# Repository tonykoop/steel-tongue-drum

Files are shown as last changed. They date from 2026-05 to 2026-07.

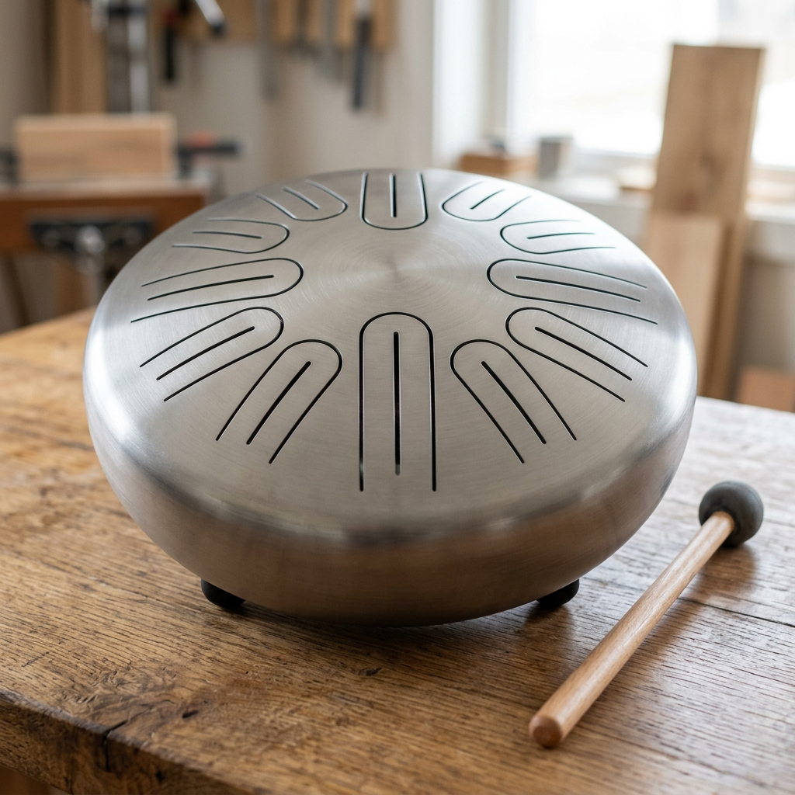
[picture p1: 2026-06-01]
images/hero-render.png

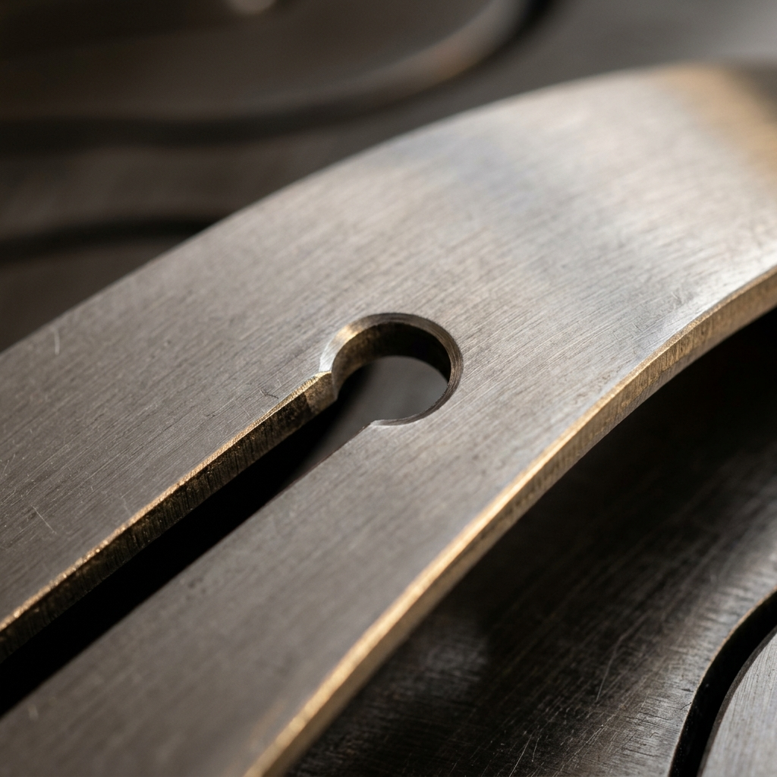
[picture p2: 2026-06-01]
images/macro/tongue-slot-root.png

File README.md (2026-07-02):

# Steel Tongue Drum

Root-mode engineering packet for a tunable steel tongue drum: a slit-tongue steel idiophone whose final tuning must be measured and corrected on the actual prototype.

**Status:** L2 V5 build-packet candidate / prototype planning. This repo is
not L3, measured, or build-ready evidence yet; slot geometry, heat/stress
behavior, tuning response, support shift, finish shift, and safety checks
still require logged prototype measurements.

This repo is part of the [tonykoop/instrument-maker](https://github.com/tonykoop/instrument-maker) catalogue and uses the `instrument-maker-v4` root packet shape.

## What this is

This packet turns the existing `steel-tongue-drum-design-table.xlsx` into a prototype-planning documentation set for a circular steel tongue drum. The workbook provides first-pass geometry, material constants, target MIDI notes, a rough Helmholtz body estimate, and tongue length formulas.

The important caveat: steel tongue drums are empirical instruments. The cantilever equation is useful for rough layout, but final pitch depends on steel batch, residual stress, slot kerf, heat affected zone, burrs, mounting isolation, mallet hardness, finish mass, and the way each tongue is trimmed. This repo is therefore not "tuned" until measured prototype data exists in `validation.csv`.

## Current design baseline

| Item | Baseline |
| --- | --- |
| Body form | Round steel shell / vessel |
| Outside diameter | 12 in assumption from workbook |
| Shell height | 6 in assumption from workbook |
| Steel thickness | 0.079 in derived from workbook input |
| Slot kerf | 0.040 in workbook assumption |
| Tongue width | 1.0 in workbook assumption |
| Port diameter | 2.5 in workbook assumption |
| Tuning reference | A4 = 440 Hz |
| Governing model | `f = K_steel * t / L^2`, first-pass only |
| Validation state | No measured prototype data yet |

## Predicted vs measured

| Category | Current packet status | What still needs physical measurement |
| --- | --- | --- |
| Tongue lengths and target notes | First-pass predictions from the workbook and `design.md` | First-strike Hz, cents error, and trim history for every tongue |
| Steel thickness and K behavior | 0.079 in and workbook K treated as assumptions | Actual sheet thickness, steel grade, and back-solved effective K after tuning |
| Cutting process | Laser / waterjet / CNC options documented | Actual kerf, burr condition, HAZ or taper, and any warp from the chosen process |
| Shell / port behavior | Port and body resonance treated as support variables | Actual port diameter, internal geometry, mount-dependent sustain, and any shell-coupled pitch shift |
| Final readiness | Private-prototype ready packet | Measured rough-cut, deburr, tuning-pass, final-mount, finish-cure, and drift-check data |

## Physical measurements still needed

- Steel grade or best-available supplier spec for the actual blank.
- Thickness measurements at multiple points on the real shell or top plate.
- Kerf coupon results for the chosen cutting method, including burr and taper notes.
- First-strike Hz for bass plus every numbered tongue before trimming.
- Cents error before tuning, after tuning, after final mounting, after finish cure, and after 24-72 hour rest.
- Port diameter and any change after deburring or finish.
- Support-condition notes for temporary cradle versus final feet.

## Packet map

- `design.md` - design intent, assumptions, formulas, tuning workflow.
- `family-spec.csv` - root-mode family row for the current steel tongue drum.
- `bom.csv`, `sourcing.csv`, `cut-list.csv` - purchasing and shop prep.
- `assembly-manual.md` - rough build, cutting, tuning, finish, and mount steps.
- `validation.csv` - tuning and process validation rows, including rough-cut, deburr, first strike, tuning pass, final mount, and drift check.
- `validation-report.md` - current readiness call, acceptance gates, and human-owned measurement work.
- `data/coupon-cam-cad-log.csv` - coupon evidence capture table for CAM/CAD promotion decisions.
- `v5-packet-surface.md` - V5 authority map, no-MCP provenance note, and
  coupon-first promotion gates for issue #5.
- `drawing-brief.md`, `drawings/` - drawing requirements and starter layout SVG.
- `explorer.html` - issue #5 explorer surface for packet status, authority boundaries, and measurement gates.
- `visual-output-register.csv` - visual authority register for the workbook, measurement template, and layout SVG.
- `cad/`, `cnc/`, `jigs/` - SolidWorks/CAM/fixture briefs, the parametric `cad/steel-tongue-drum.scad` build-envelope + tongue-cut-layout master, the issue #5 coupon-first CAM/CAD authority gate, and `cad/mcp-session-log.md` provenance log.
- `evolution/` - StudioPipeline evolution-pipeline Stage 0 intake (master manifest, design-intent, revisions).
- `images/`, `data/`, `wolfram/` - starter folders for future photos, measured results, notebook notes, and the measurement capture plan.
- `issue-comment-draft.md` - sprint-ready issue summary for `tonykoop/steel-tongue-drum#1`; do not post automatically.
- `risks.md` - acoustic, structural, ergonomic, supply, and finish risks with tests.
- `capstone-deck.md`, `print-packet.md`, `print-packet.html`, `site/index.html` - review and presentation layers.

## Readiness

This packet is private-prototype planning ready. It should stay private for public technical review until a rough-cut prototype is struck, tuned, mounted, drift-checked, and logged with measured Hz and cents error.

## Round 3 L2 Boundary

For the Round 3 build-packet sweep, treat this repo as an L2 root-mode packet:
complete enough for design review, sourcing review, and first prototype
planning, but not L3/build-ready evidence. The existing workbook and packet
tables define a controlled measurement path; they do not replace measured
strike data from a real steel shell.

The acceptance line for L3 is unchanged: every tongue needs target Hz, measured
Hz, cents error, support condition, trim history, final mount shift, finish
shift, and 24-72 hour drift logged in `validation.csv`.

## Issue 5 CAM/CAD Coupon Gate

Issue #5 is not complete yet. The repo now has an explicit
`cnc/coupon-first-cam-cad-gate.md` and `data/coupon-cam-cad-log.csv` so the
first coupon can promote or block CAD/DXF/CAM decisions with evidence. Until
that coupon row contains real material, kerf, taper, burr/HAZ/warp, and strike
measurements, the starter SVG, workbook, CAD brief, and CNC brief remain
documentation and prototype-planning artifacts only.

Round 2 recovery adds the V5 packet surface without changing that authority
boundary: `visual-output-register.csv` now marks current geometry-related rows
as `pending_measurement` or `concept_only`, and `cad/mcp-session-log.md`
records that no MCP/CAD/measurement tool session was available or used.

## License

[CC BY 4.0](LICENSE) - see LICENSE for details.

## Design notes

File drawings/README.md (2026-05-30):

# Drawings

This folder is reserved for future manufacturable drawings and exported views.
The current SVG is a starter layout brief, not a final tuned DXF.

Required future exports:

- Top slot layout DXF/SVG with actual kerf compensation.
- Section view through shell, port, and support feet.
- Slot-root detail with minimum radius and burr limit.
- Fixture/cradle drawing.

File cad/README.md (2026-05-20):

# CAD Starter

CAD should be driven from the workbook and `family-spec.csv`, but final tuned slot geometry must come from measured prototype correction.

Current status for issue #5: no repo-local coupon evidence exists yet, so CAD
is still a starter brief and not machine-ready authority. Use
`cnc/coupon-first-cam-cad-gate.md` and `data/coupon-cam-cad-log.csv` before
promoting any CAD/DXF export.

## Suggested Files

- `STD-001_MasterLayout.SLDPRT` - master sketch with shell, port, tongues, root radii, and datum axes.
- `STD-001_TongueField.DXF` - waterjet/laser/CNC export after kerf compensation.
- `STD-001_ValidationCoupon.DXF` - kerf and HAZ test coupon.

## Global Variables

- `BodyDiameter = 12 in`
- `ShellHeight = 6 in`
- `SteelThickness = measured actual`
- `KerfWidth = measured process value`
- `TongueWidth = 1 in`
- `PortDiameter = 2.5 in`

Do not lock CAD dimensions as final tuned values until `validation.csv` has measured data.
Do not mark `STD-001_TongueField.DXF` or any CAM export as build-ready until a
validation coupon has measured kerf, edge condition, and process notes logged.

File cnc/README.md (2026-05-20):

# CNC / Cutting Plan

## Preferred Prototype Path

Do not start with the full tongue field. Start with a coupon that uses the same material, process, and nominal kerf as the intended build. The coupon's job is to reveal real kerf, edge taper, burr behavior, and whether the chosen process pushes the first strike noticeably sharp or flat before the actual drum is cut.

Issue #5 gate file: `coupon-first-cam-cad-gate.md`.
Coupon evidence log: `../data/coupon-cam-cad-log.csv`.

## Process Comparison

| Process | Strength | Risk | Required validation |
| --- | --- | --- | --- |
| Waterjet | Low heat input | Edge taper, abrasive texture, burr | Measure slot width top and bottom, log burr cleanup, compare first strike before and after deburr |
| Fiber laser | Fast, accurate | HAZ, stress, warp, hard edge | Photograph discoloration, check flatness, and compare coupon pitch before and after stress relief |
| CNC mill | Controlled geometry | Fixturing thin steel, chatter, burrs | Prove hold-down, coolant/chip control, and slot finish on coupon before real cutting |
| Manual abrasive | Accessible | Low repeatability | Use only for tuning corrections, not full layout |

## Coupon-First Validation Path

1. Cut a simple coupon with one representative tongue, one slot-end radius, and one kerf sample.
2. Measure actual kerf at multiple points and record top/bottom taper if present.
3. Deburr in the intended shop sequence and note whether measured pitch changes.
4. Inspect the slot root for cracks, gouges, or over-thinning.
5. Only then cut the real top or shell tongue field.

## Manufacturing Release Gates

- The first setup must include a coupon or sacrificial strip.
- Every slot end must be radiused; no sharp internal corners.
- The layout must keep a stable orientation mark and datum so the tuning log matches the physical instrument.
- Actual kerf and any CAM compensation must be written into `validation.csv` or `data/measurement-capture-plan.md`.
- The coupon result and CAM compensation decision must be written into `data/coupon-cam-cad-log.csv`.
- No file in this folder should be described as build-ready G-code until coupon evidence and first-strike measurements exist.

## CAM Notes

- Use rounded slot termini.
- Avoid sharp internal corners.
- Keep a consistent datum/orientation mark.
- Include the validation coupon in the first setup.
- Document actual kerf and any compensation used.

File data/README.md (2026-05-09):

# Data

Measured steel tongue drum results should be stored here once cutting and tuning begin.

## Expected Artifacts

- Rough-cut and post-deburr pitch logs.
- Kerf coupon measurements and process notes.
- Before/after tuning pass results.
- Final-mount and drift-check readings.
- Photos or screenshots that support `validation.csv` entries.
- The filled measurement path from `measurement-capture-plan.md`.

## Current Status

No measured prototype data exists yet. The repo is documentation-complete enough to guide a build, but this folder should remain empty until a real prototype is logged.

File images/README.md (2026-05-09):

# Images

This folder is reserved for public-safe build photos, validation setup photos, and final hero shots once a real prototype exists.

## Priority Shots

- Raw shell or blank with steel spec visible.
- Thickness-caliper confirmation.
- Layout before cutting.
- Rough-cut and deburred tongue roots.
- First-strike tuner setup.
- Final mounted underside and finished top view.

## Current Status

No real prototype photos exist yet. Until then, `drawings/steel-tongue-drum-layout.svg` and the site packet carry the visual explanation.

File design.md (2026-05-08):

# Steel Tongue Drum Design

Generated: 2026-05-08

## Intent

Create a traceable root-mode packet for a tuned steel tongue drum. The packet documents the first-pass geometry from `steel-tongue-drum-design-table.xlsx`, the manufacturing assumptions that can move pitch, and the validation workflow needed to turn estimates into a tuned instrument.

This design is intentionally conservative about claims. The workbook formulas size tongues from a cantilever model, but the final instrument must be tuned by measured cutting and strike tests.

## Source Artifacts

| Source | Role | Status |
| --- | --- | --- |
| `steel-tongue-drum-design-table.xlsx` | Design table and first-pass geometry | Present |
| `README.md` | Root repo overview | Expanded in this packet |
| `instrument-maker-v4` references | Physics, sourcing, print packet, validator | Applied |
| Measured prototype data | Required for final tuning confidence | Not present |

## Workbook Inputs Used

| Parameter | Value | Unit | Source / confidence |
| --- | ---: | --- | --- |
| Shell outside diameter | 12.000 | in | workbook input, assumption |
| Shell height | 6.000 | in | workbook input, assumption |
| Steel thickness | 0.079 | in | workbook input, verify with calipers |
| Kerf width | 0.040 | in | workbook input, process-dependent |
| Tongue count | 11 | count | workbook note rows include bass row plus 10 numbered rows |
| Tongue width | 1.000 | in | workbook input, derived estimate |
| Port diameter | 2.500 | in | workbook input, derived estimate |
| Tuning standard | 440 | Hz | A4 reference |
| Selected K constant | 32098 | imperial | workbook steel table, first-pass only |

## Governing Model

Use the cantilever beam model only as an initial layout estimate:

```text
f = K_steel * t / L^2
L = sqrt(K_steel * t / f)
```

Where:

- `f` is target frequency in Hz.
- `K_steel` is the workbook steel constant, currently 32098 for the selected steel row.
- `t` is steel thickness in inches.
- `L` is free tongue length in inches.

The model assumes an ideal fixed-free tongue. A real steel tongue drum departs from that ideal because the tongue remains part of a stressed plate/shell, is cut by a finite kerf, may be heat affected, may retain burrs, and is coupled to the vessel body and support system.

## Target Tongue Table

The values below are first-pass estimates from the workbook formula family. Treat every length as a starting cut length with trim allowance, not a final tuned dimension.

| Tongue | MIDI | Note | Target Hz | Derived length in | Derived length mm | Status |
| ---: | ---: | --- | ---: | ---: | ---: | --- |
| Bass | 50 | D3 | 146.83 | 4.16 | 105.6 | derived estimate |
| 1 | 57 | A3 | 220.00 | 3.39 | 86.2 | derived estimate |
| 2 | 58 | A#3/Bb3 | 233.08 | 3.30 | 83.7 | derived estimate |
| 3 | 60 | C4 | 261.63 | 3.11 | 79.0 | derived estimate |
| 4 | 62 | D4 | 293.66 | 2.94 | 74.6 | derived estimate |
| 5 | 64 | E4 | 329.63 | 2.77 | 70.4 | derived estimate |
| 6 | 65 | F4 | 349.23 | 2.69 | 68.4 | derived estimate |
| 7 | 67 | G4 | 392.00 | 2.54 | 64.5 | derived estimate |
| 8 | 69 | A4 | 440.00 | 2.40 | 60.9 | derived estimate |
| 9 | 72 | C5 | 523.25 | 2.20 | 55.9 | derived estimate |
| 10 | 74 | D5 | 587.33 | 2.08 | 52.8 | derived estimate |

## Shell / Helmholtz Estimate

The workbook includes a first-pass vessel estimate using a 12 in diameter, 6 in high partial volume assumption and a 2.5 in port. This is useful for checking whether the shell may reinforce or color the tongue field, but it should not be treated as a final resonator design.

For this packet, the shell resonance is documented as a support variable:

- Verify actual internal volume after forming, welding, or purchased shell selection.
- Measure the port diameter after deburring and finish.
- Compare struck tongue spectra mounted and unmounted.
- Record whether final mounting shifts pitch or sustain.

## Empirical Tuning Workflow

1. Rough-cut the tongues long or conservative, with rounded stress-relief termini.
2. Deburr both sides without thinning the root unpredictably.
3. Strike each tongue with the same mallet and support condition.
4. Log measured Hz and cents error in `validation.csv`.
5. Remove material in controlled passes, favoring tip/length correction first.
6. Re-measure after each tuning pass and after final mounting.
7. Re-check drift after finish cure and 24-72 hours of rest.

## Manufacturing Assumptions

- Steel grade is not locked. Mild low-carbon sheet is the default planning case; stainless is acceptable only after revisiting K, cutting method, corrosion plan, and work hardening behavior.
- Thickness must be measured at the actual blank, not assumed from nominal sheet gauge.
- Laser cutting is fast but risks heat affected zones and local stress changes.
- Waterjet cutting reduces heat risk but can leave taper, abrasive edge texture, and local burrs.
- CNC milling can control slot geometry but needs serious fixturing and coolant/chip planning on thin steel.
- Every inside slot end needs a smooth radius to reduce crack initiation.

## Unresolved Tuning Assumptions

- Actual steel grade, modulus, density, hardness, and residual stress.
- Actual kerf after the chosen cutting process.
- Whether the blank is flat sheet, preformed shell, salvaged vessel, or welded assembly.
- Final support/isolation scheme.
- Mallet hardness and strike point standard.
- Finish mass and corrosion-protection method.
- Whether the bass tongue and high tongues remain balanced in volume and sustain after final trimming.

## Acceptance Criteria

The packet becomes public-review ready only after:

- Each tongue has target Hz, measured Hz, cents error, mallet condition, support condition, and environment logged.
- Rough-cut, deburr, first strike, tuning pass, final mount, and drift check rows are complete.
- At least one process note records actual kerf, burr condition, and heat/warp observations.
- `validation-report.md` is updated from measured data rather than assumptions.

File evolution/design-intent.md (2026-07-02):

# Design Intent — steel-tongue-drum rev A

- Master CAD: `cad/steel-tongue-drum.scad` (sha256: 0e1638eccd13ec92ad5bc1255719e85c75dedc66023e533947869e00f35b9f05), driven by `steel-tongue-drum-design-table.xlsx` (sha256: e1663ea1faadcabe5026d6eda636c8874fcc8eba346b22df14e118949e094d0b).
- Function: Tuned steel tongue drum (idiophone). A 12 in OD × 6 in vessel with a 0.079 in steel top plate carrying 11 radial cantilever tongues (bass D3 plus a D-centered mixed pentatonic/diatonic field to D5), struck with mallets/hands; a 2.5 in port colors the coupled shell resonance. Each tongue's pitch follows the fixed-free cantilever model f = K·t/L² (design.md Governing Model); final pitch is set empirically by trimming length. See design.md.
- Environment: indoor idiophone. Tongues are stressed plate cantilevers taking repeated strike impact; steel grade/heat treatment and cut process (laser HAZ vs waterjet taper) move pitch and crack risk.
- Target qty: 1 (root prototype). Deadline: TBD. Budget/unit ceiling: TBD.

## Critical dimensions (carry tolerances)

| Feature | Nominal | Tolerance | Why critical | Source |
| --- | --- | --- | --- | --- |
| Steel thickness t | 0.079 in | verify w/ calipers on actual blank | sets every tongue pitch (f∝t) | design.md Workbook Inputs / family-spec.csv |
| Tongue free lengths | D3 4.16 in .. D5 2.08 in | rough-cut long, tune by trim | tongue pitch (L=sqrt(K·t/f)) | design.md Target Tongue Table |
| Kerf width | 0.040 in | measured process value (coupon) | tongue width margin, tuning | design.md / cad/README.md |
| Tongue width | 1.0 in | layout | radiation/sustain balance | design table |
| Shell OD / height | 12.0 / 6.0 in | after forming/selection | coupled shell resonance | family-spec.csv |
| Port diameter | 2.5 in | after deburr/finish | Helmholtz coloration | design.md Shell/Helmholtz |

## Incidental (free for DFM)

- Exact tongue angular clocking (even fan preserved), shell wall finish, port trim styling, mounting/isolation hardware, foot/stand interface.

## Must-nots (DFM may never violate)

- Every inside slot end MUST get a smooth stress-relief radius — square slot ends initiate cracks (design.md Manufacturing Assumptions).
- Do NOT lock CAD tongue lengths as final tuned values; rough-cut long and trim to measured pitch (design.md / cad/README.md).
- Do NOT mark any tongue-field DXF/CAM export build-ready until the coupon gate (data/coupon-cam-cad-log.csv) logs measured kerf, edge condition, and HAZ (cad/README.md).
- Do NOT switch steel grade (mild → stainless) without revisiting K, cutting method, corrosion plan, and work-hardening (design.md).

## Material intent

- Preferred: mild low-carbon steel top plate/shell (default planning case). Stainless acceptable only after re-deriving K and cut process.
- Acceptable subs: per sourcing.csv (spec-first; live prices unverified).
- Forbidden: assuming nominal sheet gauge instead of measured thickness; square (un-radiused) slot terminations.

## Stage status

Stage 0 intake complete 2026-07-01. Gate A (Alpha shop compile) NOT yet run — no concessions logged, nothing presented as shippable. All tongue lengths remain first-pass estimates (no measured prototype data).

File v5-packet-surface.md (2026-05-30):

# V5 Packet Surface - Steel Tongue Drum

Status: `L2 V5 build-packet candidate; pending measurement`.

Issue: Refs #5.

This file defines the honest V5 surface for the steel tongue drum packet. It is
a structure and authority map only. It does not add CAD geometry, DXF
coordinates, CAM setup values, measured partials, or tuning frequencies.

## Authority Summary

| Surface | Current authority | Why it is not L3 |
| --- | --- | --- |
| Workbook and family spec | `pending_measurement` | Values are workbook assumptions and first-pass planning inputs; real steel thickness, kerf, stress, and tuning response are not measured. |
| Starter SVG | `concept_only` | It is a human preview, not a DXF, CAD source, or CAM input. |
| Coupon log | `pending_measurement` | `STD-COUPON-001` is `not_run`; no material, kerf, taper, burr, HAZ, warp, or strike evidence exists. |
| Validation CSV | `pending_measurement` | It is a measurement template with open rows, not a measured performance record. |
| MCP/CAD provenance | `concept_only` | `cad/mcp-session-log.md` records that no external tool session was run in this lane. |

## Coupon-First Protocol

Before promoting any CAD, DXF, CAM, or G-code claim:

1. Select the actual material blank and record supplier/spec information or
   explicitly mark the grade unknown.
2. Measure real thickness at multiple points and record the instrument state
   used for measurement.
3. Cut a representative coupon with the same process intended for the drum.
4. Measure kerf at multiple points and record top/bottom taper or edge angle
   if visible.
5. Record burr, heat affected zone, discoloration, warp, and slot-root
   condition.
6. Strike the coupon before and after deburring only if the coupon geometry is
   safely strikeable.
7. Enter the compensation decision in `data/coupon-cam-cad-log.csv`.
8. Update `validation-report.md` before any artifact changes from
   `pending_measurement` to fabrication authority.

## V5 Gate Table

| Gate | Required evidence | Current state |
| --- | --- | --- |
| G1 material evidence | Actual blank source and measured thickness | Pending |
| G2 coupon cut | Coupon made with intended process | Pending |
| G3 kerf/taper evidence | Measured kerf and edge notes | Pending |
| G4 burr/HAZ/warp evidence | Inspection notes or photos | Pending |
| G5 coupon strike evidence | Pre/post deburr Hz if safely strikeable | Pending |
| G6 CAM compensation decision | Keep/change kerf, slot radius, or process | Blocked by G1-G5 |
| G7 full tongue-field release | Reviewed coupon result and updated register | Blocked by G6 |
| G8 tuned-instrument claim | Full `validation.csv` first-strike, trim, mount, finish, and drift data | Blocked by physical build |

## What Is Needed Next

- Run the physical coupon protocol and populate `data/coupon-cam-cad-log.csv`.
- Add real evidence paths for photos, measurement sheets, or shop notes.
- Update `visual-output-register.csv` only after measurement evidence exists.
- Replace or regenerate CAD/DXF artifacts from reviewed authority before any
  build-ready claim.
- Keep the packet at L2 until the measurement and CAD authority chain is
  complete.

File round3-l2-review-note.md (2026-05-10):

# Round 3 L2 Review Note

This repo already contains a validator-clean root-mode packet. Round 3 keeps it
at L2 for review discipline:

- The cantilever model and workbook geometry are first-pass estimates.
- No rough-cut steel shell measurements have been captured.
- No tuning-pass, final-mount, finish-cure, or drift-check data exists.
- `validation.csv` is the gate for L3, not the presence of packet files.

Acoustic basis: `instrument-maker-v4/references/new-instruments-v4.md` section
`Steel Tongue Drum` identifies the steel tongue as a cantilever-beam model,
while `references/acoustic-models.md` warns that ceramic/metal tongue drums
need material-specific measurement loops.

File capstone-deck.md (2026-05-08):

# Steel Tongue Drum Capstone
- Musical instrument documentation capstone
- Build packet: steel-tongue-drum
- Generated: 2026-05-08

---

# Project Intent
- Create a traceable root-mode packet for a tuned steel tongue drum. The packet documents the first-pass geometry from `steel-tongue-drum-design-table.xlsx`, the manufacturing assumptions that can move pitch, and the validation workflow needed to turn estimates into a tuned instrument.

_Speaker notes:_ Read design.md before committing to dimensions or sourcing decisions.

---

# Physics Model
- Use the cantilever beam model only as an initial layout estimate:

```
f = K_steel * t / L^2
L = sqrt(K_steel * t / f)
```

_Speaker notes:_ Governing equations extracted verbatim from design.md. Apply empirical corrections (NAF K2, scale offsets) only where the model permits — see references/acoustic-models.md.

---

# How To Use This Packet
- Start with design.md for intent and assumptions.
- Use bom.csv, sourcing.csv, and cut-list.csv before buying or cutting.
- Use drawing-brief.md and CAD/CNC folders before machining.
- Print the packet for shopping, shop work, and validation.

---

# File Map
- design.md: Project intent, catalog metadata, assumptions, and validation plan.
- bom.csv: Starter bill of materials with part categories, quantities, drawing refs, and notes.
- sourcing.csv: Supplier/search tracker with specs, price/date fields, lead time, substitutes, and risks.
- cut-list.csv: Rough/final stock sizes, material, grain/orientation, operations, yield, and offcuts.
- drawing-brief.md: Manufacturing drawing and technical product sketch brief.
- assembly-manual.md: Shop-facing sequence, tools, fixtures, safety, tuning, finishing, and maintenance notes.
- validation.csv: Target/measured values, tolerance, environment, result, and tuning/build action log.
- supplier-rfq.md: Supplier email/request-for-quote starter.

---

# Family Spec

| family_id | member_id | instrument_name | variant | key_or_scale | body_diameter_in | shell_height_in | steel_thickness_in | tongue_count | port_diameter_in | design_stage | validation_state | notes |
| --- | --- | --- | --- | --- | --- | --- | --- | --- | --- | --- | --- | --- |
| STD-FAM-001 | STD-001 | Steel Tongue Drum | 12 inch root prototype | D-centered mixed pentatonic/diatonic study | 12.0 | 6.0 | 0.079 | 11 | 2.5 | root-mode packet | no measured prototype data | Derived from steel-tongue-drum-design-table.xlsx; final tuning empirical. |

_Speaker notes:_ Sizes scale via the master scale factor; tuning targets are first-order Helmholtz/cantilever predictions to be empirically corrected per prototype.

---

# Build Workflow
- Design and assumptions
- Source materials and hardware
- Prepare stock, fixtures, and CNC/laser/lathe setup
- Assemble, tune, finish, and validate

---

# Sourcing And BOM
- BOM gives part categories and drawing references.
- Sourcing tracks search terms, supplier candidates, price/date, lead time, substitutions.
- Visual BOM brief turns the parts list into a presentation-ready image board.

---

# Shop Packet
- Cut list for lumber/sheet/blank planning.
- Assembly manual for away-from-keyboard work.
- Validation sheet for measured dimensions, tuning, pass/fail checks.

---

# Drawings, CAD, CNC
- drawing-brief.md defines required views, dimensions, datums, sketch intent.
- cad/ holds models and design tables.
- cnc/ holds CAM, toolpaths, setup sheets, dry-run notes.
- drawings/ holds PDFs, SVGs, DXFs, drawing exports.



---

# Images And Screenshots
- Add hero render/photo, visual BOM, shop screenshots, drawing previews, validation photos in images/.

---

# Validation Plan
- A4 = 440 Hz reference check.
- Tuning targets logged in validation.csv.
- Critical dimensions verified against design sheet and CAD.
- Photos and revision notes after each major step.

---

# Open Risks / Decisions
- TBDs in design sheet and BOM.
- Supplier price/availability not yet verified.
- Generated images marked as concept placeholders.
- Empirical corrections await measured prototype data.

---

# Next Actions
- Replace TBDs with measured/source-backed values.
- Verify live supplier price and availability before buying.
- Export final drawings and visual BOM images.
- Regenerate this deck and print packet after final edits.

---

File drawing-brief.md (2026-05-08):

# Drawing Brief

## Required Drawing Set

1. Top layout with all tongue slots, centerline, port, rim, and orientation mark.
2. Section view through shell showing top thickness, shell height, port, support feet, and rim/edge treatment.
3. Detail view of a tongue root with slot-end radius, kerf, burr limit, and stress-relief note.
4. Fixture view showing temporary tuning support and final isolation feet.
5. Process coupon drawing for kerf and HAZ validation.

## Critical Dimensions

- 12.0 in body diameter assumption.
- 6.0 in shell height assumption.
- 0.079 in steel thickness assumption.
- 0.040 in kerf assumption.
- 1.0 in tongue width assumption.
- 2.5 in port diameter assumption.
- Tongue lengths from `design.md` are derived estimates and must be marked "rough-cut; tune by measurement."

## Drawing Rules

- Units: inches with metric equivalents where useful.
- Include title block, revision, date, material, finish, and "not final tuned dimensions" note.
- Show datum A as top center, datum B as rim plane, datum C as orientation line.
- Call out all inside slot ends as smooth radiused transitions.
- Do not publish as final manufacturing drawing until validation data exists.

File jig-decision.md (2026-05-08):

# Jig Decision

## Decision

Use a two-stage jig approach:

1. A non-marring temporary tuning cradle that supports the shell consistently while leaving the tongue field free.
2. A final isolation-foot layout that is re-measured after installation.

## Why

The support condition is part of the instrument. A rigid clamp, bench pad, hand hold, rubber foot, and display stand can all change damping and perceived pitch. Separating the temporary tuning cradle from the final mount makes that shift visible in `validation.csv`.

## Requirements

- Cradle must locate the shell repeatably without contacting vibrating tongues.
- Contact points should be soft enough to prevent rattles but stable enough for repeatable measurements.
- Fixture should expose the port and underside for inspection.
- Final feet must be installed before the final-mount validation phase.

## Rejected Options

- Freehand holding during tuning: too variable.
- Clamping the shell rigidly to a bench: likely to damp shell modes.
- Tuning only after final finish: hides process causes and makes correction harder.

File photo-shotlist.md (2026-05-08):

# Photo Shotlist

- Raw steel shell or blank with label/spec visible.
- Caliper reading of actual steel thickness.
- Layout on top surface before cutting.
- Kerf coupon or test cut close-up.
- Rough-cut slots before deburring.
- Deburred slot root close-up with light showing radius.
- Temporary tuning support setup.
- Tuner/microphone placement during first strike.
- Tuning pass in progress with tool and tongue identified.
- Final feet or isolation mount underside.
- Finished top view with all tongues visible.
- Detail of port, rim, and edge trim.

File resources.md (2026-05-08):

# Resources

## Local Packet Sources

- `steel-tongue-drum-design-table.xlsx` - workbook source for dimensions, K constants, target notes, and formulas.
- `design.md` - narrative design basis and assumptions.
- `validation.csv` - required measurement log.
- `drawings/steel-tongue-drum-layout.svg` - starter layout drawing.

## Instrument Maker References

- `instrument-maker-v4/references/new-instruments-v4.md` - steel tongue drum entry.
- `instrument-maker-v4/references/acoustic-models.md` - cantilever beam formulas and guard rules.
- `instrument-maker-v4/references/manufacturing-and-cnc.md` - machining and fixture guidance.
- `instrument-maker-v4/references/sourcing-and-production.md` - sourcing, RFQ, cut list, validation guidance.

## Sister Repos

- `tongue-drum` - wooden slit tongue drum done-bar reference and DoE pattern.
- `glockenspiel` - metal bar idiophone sibling concept.
- `handpan` - steel shell idiophone sibling, but different governing model.

## Measurement Tools To Use

- Chromatic tuner or spectral analysis app.
- Calipers for thickness, kerf, port, and slot checks.
- Consistent microphone placement.
- Temperature/humidity record for each tuning session.

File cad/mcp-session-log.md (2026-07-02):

# MCP Session Log

Status: `no tool session run`.

This V5 provenance stub is intentionally empty of CAD or creative-tool output.
The Round 2 recovery lane had no MCP, OpenSCAD, Blender, Illustrator,
Photoshop, Fusion, SolidWorks, Wolfram execution, or physical measurement
session available. No CAD geometry, DXF coordinates, tuning frequencies, or
measured dimensions were generated in this lane.

| session_id | tool | input_authority | outputs | role | authority_result | review_status | notes |
| --- | --- | --- | --- | --- | --- | --- | --- |
| NO-MCP-2026-05-29-R2 | none | `visual-output-register.csv`; `cnc/coupon-first-cam-cad-gate.md`; `data/coupon-cam-cad-log.csv` | none | provenance_stub | concept_only | self_checked | Records absence of tool execution; all geometry and tuning authority remains pending measurement. |
| fable-v5-refresh-2026-07-01 | claude-code (Fable 5) + OpenSCAD CLI | steel-tongue-drum-design-table.xlsx, design.md, family-spec.csv | cad/steel-tongue-drum.scad | cad_authoring | pending_measurement | self_checked | Parametric build-envelope + tongue-cut LAYOUT master (equation-driven L=sqrt(32098*t/f)). openscad render check: pass (openscad -o STL, exit 0, Simple: yes). NOT fabrication authority — kerf/slot-radii/HAZ/tuned-trim out of scope pending coupon gate. |
| fable-v5-refresh-2026-07-01 | claude-code (Fable 5) | steel-tongue-drum-design-table.xlsx | wolfram/steel-tongue-drum-wolfram-model.wl | analysis_source | derived_preview | unreviewed | Register row added for the epic197-deployed Wolfram model source; not executed — source-only L2 evidence. |

## Promotion Rule

If a future lane uses OpenSCAD, Blender, Illustrator, Photoshop, Fusion,
SolidWorks, Wolfram, or another external tool to create or modify packet
artifacts, add a real session row before describing any output as reviewed,
derived, or fabrication authority.

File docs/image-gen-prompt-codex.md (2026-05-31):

# Image-Gen Prompt - Steel Tongue Drum

Concept image only; not fabrication authority. Do not include cut-ready dimensions, tongue slot coordinates, port patterns, or toolpaths.

## Hero Prompt

Photorealistic studio product photograph of a finished circular steel tongue drum with a rounded steel shell, eleven slit-cut tongues including a larger bass tongue, a small resonating port, smooth deburred slot ends, satin powder-coated or brushed finish, and a pair of soft mallets resting nearby. Show realistic handpan-like scale without copying a brand, clean studio background, three-quarter product angle from above, soft directional studio lighting, approximately 50mm lens, high detail.

## In-Context Prompt

Photorealistic image of the steel tongue drum being played on a lap or low stand in a quiet recording room, soft mallets striking two different tongues, natural light, a tuner and validation notebook blurred nearby, realistic posture, rounded safe edges, calm prototype-review atmosphere.

## Detail/Macro Prompt

Macro photorealistic close-up of a single slit tongue and neighboring slots, showing rounded stress-relief termini, deburred edge, subtle finish texture, soft mallet tip just above the tongue, and shallow curvature of the steel shell, shallow depth of field, crisp highlights.

## Negative/Avoid

No text, no watermarks, no brand marks, no fake note labels, no cut-ready tongue layout, no sharp burrs or cracked slots, no extra limbs, anatomically plausible hands.

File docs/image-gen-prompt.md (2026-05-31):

# Image-Gen Prompts

Concept image only; not fabrication authority. Do not include cut-ready dimensions, hole locations, or toolpaths.

## Hero Prompt

A finished circular steel tongue drum photographed as a real, hand-built idiophone: a round low-profile steel shell, roughly the proportions of a small drum that fits in two hands, with a domed or gently rounded top plate cut with a radial fan of eleven slit tongues of graduated length splaying out from the center toward the rim. The tongues read clearly as cut slots in the steel surface, each terminating in a smooth rounded slot-end, the longest bass tongue prominent and the shorter high tongues stepping down in size around the field. Brushed low-carbon steel with a subtle satin clear finish, faint mill grain catching the light, softly radiused rim, no welds or seams emphasized. Three rubber feet barely visible at the base lift the body slightly off the surface. Realistic tabletop scale cues, a soft-tipped mallet resting beside it. Clean neutral studio background, soft directional studio light raking across the top to reveal the tongue slots, 3/4 product-photography angle, ~50mm lens, high detail, photorealistic, no text labels.

## In-Context Prompt

A steel tongue drum staged on a worn wooden workbench in a metal-fabrication workshop, soft natural window light, a pair of soft mallets and a small handful of deburring files nearby, faint steel dust and a coupon test-cut offcut in the background telling the story of an empirical, tuned-by-hand instrument. A hand hovers over the longest tongue mid-strike. Warm raking daylight catches the brushed steel top and the radial slit pattern, shallow depth of field with the tongue field in sharp focus and the shop softly blurred behind, environmental storytelling, concept visualization only.

## Detail Prompt

Macro close-up of the signature mechanism: the root of a single cut steel tongue where the slit terminates in a smooth radiused slot-end, the cut kerf running cleanly through brushed steel, a faint deburred chamfer along the slot edge catching the light. Show the satin tooled texture of the steel, the subtle warmth of a clear protective finish, and the gentle curvature of the top plate. Raking light grazes the slot to reveal depth and edge quality, high detail, no measurements.

## Negative / Avoid

No text/logos/watermarks/fake maker marks, no dimension callouts, no impossible mechanisms; anatomically plausible hands if a player is shown.

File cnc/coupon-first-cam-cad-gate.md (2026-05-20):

# Coupon-First CAM/CAD Authority Gate

Current status: `blocked-no-coupon-evidence`.

This gate separates validator-clean documentation from machine-ready authority.
The workbook, family spec, starter SVG, and packet docs can guide a first
prototype review, but they do not authorize final CAD, DXF, CAM compensation,
or G-code until coupon evidence is captured from the real material and process.

## Current Authority Boundary

| Artifact | Current role | Machine-ready status |
| --- | --- | --- |
| `steel-tongue-drum-design-table.xlsx` | Planning design table | Not final tuned geometry |
| `family-spec.csv` | Family/member assumptions | Not measured material authority |
| `drawings/steel-tongue-drum-layout.svg` | Derived preview | Not DXF, CAM, or cut authority |
| `cad/README.md` | CAD intent brief | No reviewed CAD source present |
| `cnc/README.md` | Coupon-first process brief | No released CAM setup present |
| `data/coupon-cam-cad-log.csv` | Evidence capture template | No coupon result logged yet |

## Required Coupon Evidence

Before any file is described as final CAD/CAM, record:

- actual material grade or best-available supplier description;
- actual thickness measurements from the real blank;
- cutting process, machine, nozzle/tool, speed/feed/power notes where known;
- measured kerf at multiple coupon locations;
- top/bottom taper or edge angle notes;
- burr, heat affected zone, discoloration, warp, and slot-root condition;
- pre-deburr and post-deburr strike Hz if the coupon geometry supports a strike;
- compensation decision: keep workbook kerf, change kerf, change slot radius, or change process.

## Promotion Rules

- `STD-001_ValidationCoupon.DXF` may be promoted from planned to coupon-ready
  after it includes datum, material, thickness, nominal kerf, root radius, and
  "coupon only; not full drum CAM" notes.
- `STD-001_TongueField.DXF` remains blocked until coupon measurements are
  logged and the kerf/slot-radius decision is updated.
- Any CAM setup remains blocked until the coupon row records process evidence
  and the validation report explains whether the process is acceptable.
- Public build-ready or L3 language remains blocked until measured first-strike,
  tuning-pass, mount, finish, and drift evidence exists for the full instrument.

## Issue 5 Status

For issue #5, this repo now has an explicit coupon-first CAM/CAD gate and a
log template, but the gate remains blocked because no physical coupon evidence
is present in the repository.

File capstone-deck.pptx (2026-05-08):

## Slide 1

Steel Tongue Drum Capstone

Musical instrument documentation capstone
Build packet: steel-tongue-drum
Generated: 2026-05-08

Steel Tongue Drum Capstone | Slide 1 of 14

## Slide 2

Project Intent

• Create a traceable root-mode packet for a tuned steel tongue drum. The packet documents the first-pass geometry from `steel-tongue-drum-design-table.xlsx`, the manufacturing assumptions that can move pitch, and the validation workflow needed to turn estimates into a tuned instrument.

Steel Tongue Drum Capstone | Slide 2 of 14

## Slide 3

Physics Model

• Use the cantilever beam model only as an initial layout estimate:
f = K_steel * t / L^2
L = sqrt(K_steel * t / f)

Steel Tongue Drum Capstone | Slide 3 of 14

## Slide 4

How To Use This Packet

• Start with design.md for intent and assumptions.
• Use bom.csv, sourcing.csv, and cut-list.csv before buying or cutting.
• Use drawing-brief.md and CAD/CNC folders before machining.
• Print the packet for shopping, shop work, and validation.

Steel Tongue Drum Capstone | Slide 4 of 14

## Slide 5

File Map

• design.md: Project intent, catalog metadata, assumptions, and validation plan.
• bom.csv: Starter bill of materials with part categories, quantities, drawing refs, and notes.
• sourcing.csv: Supplier/search tracker with specs, price/date fields, lead time, substitutes, and risks.
• cut-list.csv: Rough/final stock sizes, material, grain/orientation, operations, yield, and offcuts.
• drawing-brief.md: Manufacturing drawing and technical product sketch brief.
• assembly-manual.md: Shop-facing sequence, tools, fixtures, safety, tuning, finishing, and maintenance notes.
• validation.csv: Target/measured values, tolerance, environment, result, and tuning/build action log.
• supplier-rfq.md: Supplier email/request-for-quote starter.

Steel Tongue Drum Capstone | Slide 5 of 14

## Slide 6

Family Spec

family_id | member_id | instrument_name | variant | key_or_scale | body_diameter_in | shell_height_in | steel_thickness_in | tongue_count | port_diameter_in | design_stage | validation_state | notes
STD-FAM-001 | STD-001 | Steel Tongue Drum | 12 inch root prototype | D-centered mixed pentatonic/diatonic study | 12.0 | 6.0 | 0.079 | 11 | 2.5 | root-mode packet | no measured prototype data | Derived from steel-tongue-drum-design-table.xlsx; final tuning empirical.

Steel Tongue Drum Capstone | Slide 6 of 14

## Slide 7

Build Workflow

• Design and assumptions
• Source materials and hardware
• Prepare stock, fixtures, and CNC/laser/lathe setup
• Assemble, tune, finish, and validate

Steel Tongue Drum Capstone | Slide 7 of 14

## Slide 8

Sourcing And BOM

• BOM gives part categories and drawing references.
• Sourcing tracks search terms, supplier candidates, price/date, lead time, substitutions.
• Visual BOM brief turns the parts list into a presentation-ready image board.

Steel Tongue Drum Capstone | Slide 8 of 14

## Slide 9

Shop Packet

• Cut list for lumber/sheet/blank planning.
• Assembly manual for away-from-keyboard work.
• Validation sheet for measured dimensions, tuning, pass/fail checks.

Steel Tongue Drum Capstone | Slide 9 of 14

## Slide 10

Drawings, CAD, CNC

• drawing-brief.md defines required views, dimensions, datums, sketch intent.
• cad/ holds models and design tables.
• cnc/ holds CAM, toolpaths, setup sheets, dry-run notes.
• drawings/ holds PDFs, SVGs, DXFs, drawing exports.

Steel Tongue Drum Capstone | Slide 10 of 14

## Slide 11

Images And Screenshots

• Add hero render/photo, visual BOM, shop screenshots, drawing previews, validation photos in images/.

Steel Tongue Drum Capstone | Slide 11 of 14

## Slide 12

Validation Plan

• A4 = 440 Hz reference check.
• Tuning targets logged in validation.csv.
• Critical dimensions verified against design sheet and CAD.
• Photos and revision notes after each major step.

Steel Tongue Drum Capstone | Slide 12 of 14

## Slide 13

Open Risks / Decisions

• TBDs in design sheet and BOM.
• Supplier price/availability not yet verified.
• Generated images marked as concept placeholders.
• Empirical corrections await measured prototype data.

Steel Tongue Drum Capstone | Slide 13 of 14

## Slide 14

Next Actions

• Replace TBDs with measured/source-backed values.
• Verify live supplier price and availability before buying.
• Export final drawings and visual BOM images.
• Regenerate this deck and print packet after final edits.

Steel Tongue Drum Capstone | Slide 14 of 14

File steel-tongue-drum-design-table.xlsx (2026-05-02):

Steel Tongue Drum — Cantilever Beam + Helmholtz Cavity
Lenticular steel shell with CNC/laser-cut tongues · Same f = K×t/L² physics as wood tongue drum · Enclosed shell adds Helmholtz resonance
DESIGN INPUTS
Shell Diameter (in) | 12.0 | ← 6-14" typical; 12" is standard
Shell Height (in) | 6.0 | ← Total height of both halves glued together
Steel Thickness (in) | 0.079 | ← 2mm (14 ga); 1.5-3mm range
Slit Kerf Width (in) | 0.040 | ← Laser=0.01", Plasma=0.04"
Number of Tongues | 11 | ← 8-15 typical; 11 or 13 for pentatonic + octave
Tongue Width (in) | 1.000 | ← Width does NOT affect pitch (L² dominant)
Steel Type | Carbon Steel | ← Carbon, 304 Stainless, or 430 Stainless
Sound Port Diameter (in) | 2.5 | ← Bottom center hole; 2-3" typical
Reference Pitch (Hz) | 440
Scale Selection | D Kurd | ← See Scale Library below
STEEL MATERIAL LIBRARY — Cantilever K Constants
Steel Type | E (GPa) | ρ (kg/m³) | K (imperial) | Tone Character | Rust? | Cut Method
Carbon Steel (1018/1020) | 200 | 7850 | 32098 | Warm, rich sustain; traditional | Yes — needs coating | Laser, plasma, or CNC
304 Stainless Steel | 193 | 8000 | 31234 | Bright, bell-like; long sustain | No | Laser or CNC (hard on plasma)
430 Stainless Steel | 200 | 7700 | 32409 | Balanced; good tuning stability | No | Laser or CNC
Spring Steel (1095) | 210 | 7850 | 32891 | Crisp, clear; excellent sustain | Yes — needs coating | Laser only (too hard for CNC)
Corten / Weathering Steel | 200 | 7850 | 32098 | Warm; develops patina; artistic | Controlled rust (patina) | Laser or plasma
← K = (1.875²/2π)×√(E/(12ρ))/0.0254 — same Euler-Bernoulli as wood Tongue Drum sheet
Selected Steel K: | 32098
HELMHOLTZ CAVITY RESONANCE
Chamber Volume (in³)
Port Area (in²)
Effective Neck Length (in)
Helmholtz Freq (Hz)
Nearest Note
← Helmholtz bass fills in below the lowest tongue — play by cupping/uncupping the port
SCALE LIBRARY — Common Steel Tongue Drum Tunings
Scale | Notes (11-note) | Mood
D Kurd (Aeolian) | D3 A3 Bb3 C4 D4 E4 F4 G4 A4 Bb4 C5 | Versatile minor
D Celtic Minor | D3 A3 C4 D4 E4 F4 G4 A4 C5 D5 E5 | Open, spacious
C Major (Ionian) | C3 G3 A3 B3 C4 D4 E4 F4 G4 A4 C5 | Bright, joyful
D Akebono | D3 A3 Bb3 D4 E4 A4 Bb4 D5 E5 A5 Bb5 | Zen, Japanese
C# Pygmy | C#3 G#3 B3 C#4 D#4 G#4 B4 C#5 D#5 G#5 B5 | Dreamy, grounding
E Hijaz | E3 B3 C4 D#4 E4 F4 G#4 A4 B4 C5 E5 | Exotic, Middle Eastern
Pentatonic G Major | G3 A3 B3 D4 E4 G4 A4 B4 D5 E5 G5 | Universally pleasant
Pentatonic A Minor | A3 C4 D4 E4 G4 A4 C5 D5 E5 G5 A5 | Meditative, calming
TONGUE LENGTH CALCULATOR — Cantilever: f = K × t / L² → L = √(K × t / f)
← Width affects volume/sustain but NOT frequency. Length is dominant (L² in denominator).
# | Note | MIDI | Freq (Hz) | Tongue Length (in) | Tongue Length (mm) | Width (in) | Slit Total (in) | Fits?
Ding | D3 | 50
1 | A3 | 57
2 | Bb3 | 58
3 | C4 | 60
4 | D4 | 62
5 | E4 | 64
6 | F4 | 65
7 | G4 | 67
8 | A4 | 69
9 | C5 | 72
10 | D5 | 74
BILL OF MATERIALS
# | Item | Qty | Spec / Dimensions | Supplier / Notes | Est. Cost
1 | Steel tank / propane tank | 1 | 12 in diam, ~2mm wall, carbon or stainless | Empty propane tank (most common), or buy pre-drawn shells | $15-50
2 | Angle grinder + cut-off disc | 1 | 4.5 in grinder, thin cut-off wheel (1mm) | For cutting tank open and rough tongue cuts | $30-60
3 | Jigsaw with metal blade | 1 | OR plasma cutter, OR Dremel with cut-off wheel | For precise tongue slit cuts; laser cut if available | $20-50
4 | Files + deburring tools | 1 | Flat file, half-round, needle files | Smooth all cut edges; critical for tone quality | $15-30
5 | Chromatic tuner + spectrum analyzer | 1 | Peterson StroboClip or Audacity FFT | Same as handpan tuning setup | $30-100
6 | Magnets (tongue weights) | 12 | Small neodymium magnets, various sizes | Stick to underside of tongue to lower pitch for fine-tuning | $5-15
7 | Rubber feet / pads | 4 | Adhesive rubber bumpers | Isolate drum from surface; improve resonance | $5-10
8 | Paint / finish | 1 | High-temp spray paint or patina finish | Rust protection for carbon steel; decorative for stainless | $10-20
 | ESTIMATED TOTAL |  |  |  | $130-335
BUILD METHOD
# | Phase | Operation | Tools | Key Parameters
1 | Shell Prep | Acquire tank; remove valve; clean inside | Wrench, soap/water flush | SAFETY: ensure tank is completely empty and purged of gas
2 | Shell Prep | Cut tank in half at equator (top = playing surface) | Angle grinder | Mark line with tape; cut slowly; deburr edge
3 | Shell Prep | Weld or glue halves back with ~6 in gap (height) | MIG welder or epoxy | Or use two matching tanks for desired height
4 | Layout | Mark tongue pattern on top shell from center outward | Template, compass, marker | Use laser-cut acrylic template from calculator dimensions
5 | Cutting | Cut tongue slits using jigsaw or plasma cutter | Jigsaw (metal blade), OR plasma, OR laser | Cut slightly short; file to final length for pitch adjustment
6 | Cutting | Deburr and smooth all cut edges | Files, sandpaper, Dremel | Smooth edges critical for clean tone and finger safety
7 | Tuning | Check pitch of each tongue with tuner | Chromatic tuner | Tongues will be SHARP initially (too short = too high)
8 | Tuning | File tip of tongue to LOWER pitch (lengthen effective beam) | Flat file, needle file | Thinning the tip = lower freq. Shortening = higher freq.
9 | Tuning | Add magnets to underside for fine-tuning (lower pitch) | Neodymium magnets | Magnets add mass to tongue tip; easy to adjust
10 | Port | Cut or verify Gu sound port in bottom shell | Hole saw | 2.5 in port; affects Helmholtz bass and sustain
11 | Finishing | Clean, paint/seal, add rubber feet | Spray paint, rubber pads | High-temp paint for carbon steel; patina or polish for stainless
12 | Finishing | Final tuning check after finish has cured | Chromatic tuner | Paint adds slight mass; re-check all tongues
DESIGN NOTES
1. Same cantilever beam physics as your wood Tongue Drum sheet, but with steel K constants (~32,000 vs ~25,000-29,000 for wood).
2. Steel tongues are shorter than wood for same note because steel has higher K (stiffer material, similar density).
3. The enclosed shell acts as a Helmholtz resonator — this is what gives the singing sustain that open-back wood tongue drums lack.
4. WIDTH does NOT affect pitch (only volume/sustain). Wider tongues = louder, more sustain. Narrower = quieter, quicker decay.
5. Tongue tip filing is the primary tuning method: thinning the tip lowers pitch. NEVER shorten a tongue to raise pitch — you can't add metal back.
6. Neodymium magnets on tongue underside are the secret weapon for fine-tuning. Easy to add/remove, reversible.
7. Laser cutting tongue slits (Epilog at Maker Nexus) gives cleanest cuts and most accurate dimensions. Jigsaw is backup.
8. Propane tanks are the most popular DIY shell. Standard 20lb tank is ~12 in diam. Larger tanks (14-16 in) allow lower notes.
9. Unlike handpan, NO multi-partial tuning needed — each tongue produces one clean fundamental. Much easier first steel project.
10. The photo shows a commercial 13-tongue drum. Start with 8-11 tongues for your first build; add more as you gain experience.
WOLFRAM CLOUD NOTEBOOK SPEC — STEEL TONGUE DRUM
Propane-tank or sheet-steel tongue drum — Hapi-style, all-metal.
§1 — Origin & Etymology
Origin: ~2007 Hapi Drum (Dennis Havlena) — invented from a 20-lb propane tank. Spread rapidly through DIY community.
Inspired by tongue-drums + handpan. Lower cost than handpan (~$100–300 vs $1500–3000).
Wolfram items: TimelinePlot[{2007 Havlena, 2010s commercialization, present}].
§2 — Physics
Steel tongues cut into a closed steel chamber (propane tank or welded sheet). f = K_steel·t/L² (cantilever).
Chamber acts as Helmholtz: f_H = (c/2π)·√(A_holes/(V·L_neck)). Coupling tongue + chamber adds sustain.
Note: K for steel ~6× wood → tongue lengths shorter, ~3–6" for typical pentatonic range.
Wolfram functions: NDEigensystem cantilever steel; Helmholtz formula; Periodogram of struck tongue.
§3 — Geometry & Materials
20-lb propane tank: 30 cm Ø × 36 cm tall, 2.5 mm wall steel. Or welded 2 mm steel hemispheres.
Tongues cut by plasma/laser, ~3–6" long × 1.5" wide. Pentatonic or diatonic scales.
Wolfram items: Manipulate tongue lengths → pentatonic scale; ParametricPlot3D tank + cuts.
§4 — Animations
Mode 1 of each tongue Animate; sympathetic ringing across tongues.
Helmholtz cavity pressure pulsation.
§5 — Executable Cells
kSteel := (1.875^2/(2 π)) Sqrt[200 10^9 /(12·7850)] / 0.0254
lTongue[f_,t_]:=Sqrt[kSteel t / f]
fHelmTank[A_,V_,L_]:=(343/(2 π)) Sqrt[A/(V L)]
§6 — Wolfram Functions
NDEigensystem, Manipulate, Periodogram, CloudDeploy, FormFunction, APIFunction.
WOLFRAM EXPLORATIONS — STEEL TONGUE DRUM
Roadmap-inspired notebook ideas mapped to this instrument.
Sound synthesis
→ Cantilever Timbre Comparison (roadmap: filed as #35)
Synthesize same tongue length in steel vs wood vs ceramic; high K_steel → short bright tongue; high Q → long sustain.
Pentatonic Playground tablet demo — click/tap notes.
Manufacturing
→ Plasma/Laser Toolpath Animator (roadmap: G-Code Animator)
Animate the cut sequence on a 20-lb propane-tank blank; verify tongue boundaries before running plasma. Avoid heat warp by sequencing inner cuts first.
Helmholtz tuning
→ Helmholtz Resonance Tuner (roadmap)
Manipulate sound-hole area + tank volume → cavity resonance vs tongue range; tune cavity to harmonize with the lowest tongue (not coincide — detune slightly for richer sound).

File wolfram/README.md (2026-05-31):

# Wolfram

Wolfram-related notes and future notebooks live here.

## Current Source

- `../steel-tongue-drum-starter.wl` - starter source for tuning and geometry sweeps.

## Planned Follow-Ons

- Tongue-length sensitivity plots against thickness and K.
- Measured-vs-predicted cents-error plots after the first tuning pass.
- Port and support-condition comparison notes if the shell resonance becomes a meaningful variable.

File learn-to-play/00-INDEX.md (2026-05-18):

# Steel Tongue Drum — Starter Songbook

Your steel tongue drum is tuned to **D natural minor** (D Aeolian):

```
D3 (bass) — A3 — Bb3 — C4 — D4 — E4 — F4 — G4 — A4 — C5 — D5
```

The steel tongue drum plays by striking tongues cut into the top surface.
Striking speed, mallet type, and position all affect tone quality.

## Difficulty key
- ★☆☆ — Beginner: stepwise motion, slow tempo
- ★★☆ — Intermediate: larger leaps, some rhythmic complexity
- ★★★ — Advanced: full range, ornamentation

## Tunes in this songbook
1. `tunes/sakura/` ★☆☆ — Sakura Sakura, Japanese traditional (A Bb D E)
2. `tunes/simple-gifts/` ★★☆ — Simple Gifts, Shaker hymn (F major)
3. `tunes/ode-to-joy/` ★★☆ — Ode to Joy theme (D natural minor adaptation)
4. `tunes/water-is-wide/` ★★☆ — The Water Is Wide (D natural minor)
5. `tunes/dusk-bloom/` ★★★ — Dusk Bloom (original, D Aeolian)

## Mallet and striking notes
- Soft rubber or silicone mallets produce the warmest sustained tone.
- Strike each tongue near its center (not at the tip or base of the slit).
- Harder sticks produce brighter, shorter tones; softer produce fuller bloom.
- The bass tongue (D3) is the foundation — use it as a drone for improvisation.

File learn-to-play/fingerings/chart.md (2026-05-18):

# Steel Tongue Drum Tongue Reference

Your 11-tongue drum layout (D natural minor, D3 bass):

```
Physical layout (looking down at the drum top):

        ┌─────────────────────────────────┐
        │                                  │
        │   ┌──D5──┐   ┌──C5──┐          │  ← Upper tongues (high notes)
        │   └──────┘   └──────┘          │
        │  ┌──A4──┐  ┌──G4──┐           │
        │  └──────┘  └──────┘           │
        │ ┌──F4──┐ ┌──E4──┐             │
        │ └──────┘ └──────┘             │
        │ ┌──D4──┐ ┌──C4──┐             │
        │ └──────┘ └──────┘             │
        │   ┌──Bb3─┐   ┌──A3──┐         │
        │   └──────┘   └──────┘         │
        │         ┌──D3 (Bass)─┐        │  ← Bass tongue (lowest)
        │         └────────────┘        │
        └─────────────────────────────────┘
```
*(Actual layout varies by builder; verify with your drum.)*

## Striking tips
- Center of each tongue produces clearest fundamental
- Tip of tongue produces shorter, higher-pitched tone
- Base of tongue near slit produces more fundamental
- Softer mallets: more bloom, longer sustain
- Harder mallets: faster attack, cleaner articulation

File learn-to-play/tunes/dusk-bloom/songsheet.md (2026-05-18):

# Dusk Bloom — Songsheet

**Key:** D Aeolian (natural minor)  **Tempo:** ♩= 80  **Meter:** 4/4  **Difficulty:** ★★★
**Range:** D3–E4  **License:** MIT (original composition — Heifer Zephyr)

## Music
```
X:5 T:Dusk Bloom M:4/4 L:1/8 Q:1/4=80 K:Dmin
D4 A4 | d4 c4 | A4 G4 | F8 |
F4 A4 | c4 d4 | c4 A4 | G8 |
A4 c4 | d4 e4 | d4 c4 | A8 |
G4 F4 | G4 A4 | d4 c4 | D8 |
```
*(D3 bass is the opening note; use the bass tongue to anchor each phrase)*

## Character
A slow, meditative piece that uses the full range of the drum — from the bass D3
tongue up to E4. The arching phrases evoke a gradual descent from light to shadow.
Each sustained note (half notes and whole notes) should ring fully into the next.

## Notes
- Begin with the bass D3 tongue — this is the drum's foundation note.
- The E4 in bar 10 is the only departure from the D minor pentatonic core — it provides
  the harmonic "color" of the natural minor scale.
- Play with closed eyes if possible; let the overtones of each tongue guide the next note.

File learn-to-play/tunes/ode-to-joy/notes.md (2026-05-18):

# Notes: Ode to Joy (Steel Tongue Drum Adaptation)

**Provenance:** Beethoven's melody (1824), PD. This is a free adaptation into D Aeolian —
not a transcription of any copyrighted modern arrangement.

**Range check:** A3–A4. Uses the heart of the drum (tongues 1 through 8).

**Practice tips:**
1. The dotted rhythm (f3 e) = dotted quarter + eighth — count "1-and-2-AND"
2. The adaptation into D minor gives a more contemplative feel than the triumphant original.
3. Use the drone D3 bass tongue between phrases for extra resonance.

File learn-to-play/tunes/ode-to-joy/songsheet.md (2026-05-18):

# Ode to Joy — Songsheet (Steel Tongue Drum)

**Key:** D natural minor (adapted)  **Tempo:** ♩= 84  **Meter:** 4/4  **Difficulty:** ★★☆
**Range:** D4–A4  **Source:** Beethoven, Symphony No. 9 (1824), PD; adapted for D Aeolian

## Music
```
X:3 T:Ode to Joy (D Aeolian) M:4/4 L:1/8 Q:1/4=84 K:Dmin
f2 f2 g2 a2 | a2 g2 f2 e2 | d2 d2 e2 f2 | f3 e e4 |
f2 f2 g2 a2 | a2 g2 f2 e2 | d2 d2 e2 f2 | e3 d d4 |
e2 e2 f2 d2 | e2 f2 g2 f2 | d2 e2 f2 g2 | f2 e2 d2 A2 |
```

## Adaptation note
The original "Ode to Joy" is in D major. This version has been transposed to start on F (using D natural minor = F major relative) so that the familiar melody fits the drum's scale. The minor character gives it a more introspective, meditative quality than the orchestral original.

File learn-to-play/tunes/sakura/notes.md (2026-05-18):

# Notes: Sakura Sakura

**Provenance:** Traditional Japanese melody associated with cherry blossoms.
Origin: Edo period (17th–18th century). Published in "Kinkyoku Shūi" (1888), PD.
The famous koto version and all traditional arrangements are public domain.

**Range check:** A3–E4. Uses only 4 of the 11 drum tongues — perfect for beginners.

**Practice tips:**
1. The Bb (b in ABC K:Dmin) gives this tune its distinctly Japanese character — don't hurry past it.
2. Each Bb is approached from A (a half-step below) — listen for the tension and release.
3. At ♩= 72, count slowly: 1 – 2 – 3 – 4. Don't rush the whole notes (d2).
4. The bass D tongue can echo softly between phrases for ambience.

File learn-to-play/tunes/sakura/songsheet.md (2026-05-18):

# Sakura Sakura — Songsheet

**Key:** A Bb D E (In scale / Sakura pentatonic)  **Tempo:** ♩= 72
**Meter:** 4/4  **Difficulty:** ★☆☆  **Range:** A3–E4
**Source:** Traditional Japanese, Edo period (18th c.), public domain

## Music
```
X:1 T:Sakura Sakura M:4/4 L:1/4 Q:1/4=72 K:Dmin
A B d2 | A B d2 | A B d e | d B A2 |
A B d e | d B A2 | A d d B | A4 |
```
*(In K:Dmin, b = Bb. Use notes A3, Bb3, D4, E4 only.)*

## Notes
- Uses only 4 notes from your drum: **A, Bb, D, E** — the "In" (Sakura) pentatonic.
- The slow 4/4 feel should be meditative — leave space after each phrase.
- The bass D tongue can serve as a drone between phrases.

**Provenance:** Traditional Japanese koto melody, Edo period. PD worldwide.

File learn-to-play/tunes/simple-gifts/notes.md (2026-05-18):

# Notes: Simple Gifts (Steel Tongue Drum)

**Provenance:** Elder Joseph Brackett, Shaker hymn (1848). PD.
Copland's arrangement is NOT used — freshly arranged from the lead-sheet melody.

**Range check:** E4–D5. E4 is the lowest note (tongue 5), D5 is the highest (tongue 10/11).

**Practice tips:**
1. F major and D natural minor share the same notes (relative modes) — your drum was built for this.
2. The tied final note (f8-) should ring uninterrupted for 4 full beats.
3. The "arch" gesture (ascending then descending) is the structural key — practice it at ♩= 60 first.

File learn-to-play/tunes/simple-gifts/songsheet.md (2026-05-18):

# Simple Gifts — Songsheet (Steel Tongue Drum)

**Key:** F major  **Tempo:** ♩= 88  **Meter:** 4/4  **Difficulty:** ★★☆
**Range:** E4–D5  **Source:** Elder Joseph Brackett, Shaker hymn (1848), PD

## Music
```
X:2 T:Simple Gifts M:4/4 L:1/8 Q:1/4=88 K:F
f4 f2 g2 | a4 f4 | a4 b2 c'2 | d'8 |
d'2 c'2 a2 c'2 | d'4 f4 | c'4 a2 f2 | g8 |
a4 a2 g2 | f4 d'4 | c'2 a2 c'2 a2 | f8 |
f4 g2 a2 | g4 e4 | f8- | f8 |
```
*(F major: Bb is automatically b in K:F. Your drum has Bb3 — play it for the b note.)*

## Notes
- F major uses all the same notes as D natural minor (they share a key signature).
- The melody moves in smooth arches — connect notes fluidly.
- D5 (d') at the end of bar 4 is the peak — strike it confidently and let it ring.

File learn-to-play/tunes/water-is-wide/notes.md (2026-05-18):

# Notes: The Water Is Wide

**Provenance:** Traditional English/Scottish ballad. PD.
Arranged here for D natural minor — the original is commonly played in G or F major.
No copyrighted arrangement is reproduced; melody is freshly arranged.

**Range check:** E4–D5. Upper D5 appears at the emotional peak of phrase 2.

**Practice tips:**
1. The pickup note A starts before bar 1 — a soft, gentle entrance.
2. The Bb (b in K:Dmin) lends the arrangement a folk-minor quality.
3. Play at ♩= 72 if ♩= 80 feels rushed — this tune benefits from spaciousness.

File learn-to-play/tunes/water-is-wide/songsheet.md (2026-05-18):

# The Water Is Wide — Songsheet (Steel Tongue Drum)

**Key:** D natural minor (F major equivalent)  **Tempo:** ♩= 80
**Meter:** 4/4  **Difficulty:** ★★☆  **Range:** E4–D5
**Source:** Traditional, PD; arranged for D Aeolian

## Music
```
X:4 T:The Water Is Wide M:4/4 L:1/4 Q:1/4=80 K:Dmin
A | A3/2 c/ A F | G3 E | F G A B | c4 |
c3/2 c/ c A | c d c A | G3/2 A/ G F | A4 |
```
*(b = Bb; d = D5)*

## Notes
- The graceful ascending and descending phrases match the steel tongue drum's blooming resonance.
- The Bb (b in K:Dmin) gives the folk color — lean into it slightly.
- This is the most "singing" tune in the set — play with feeling and slight rubato.

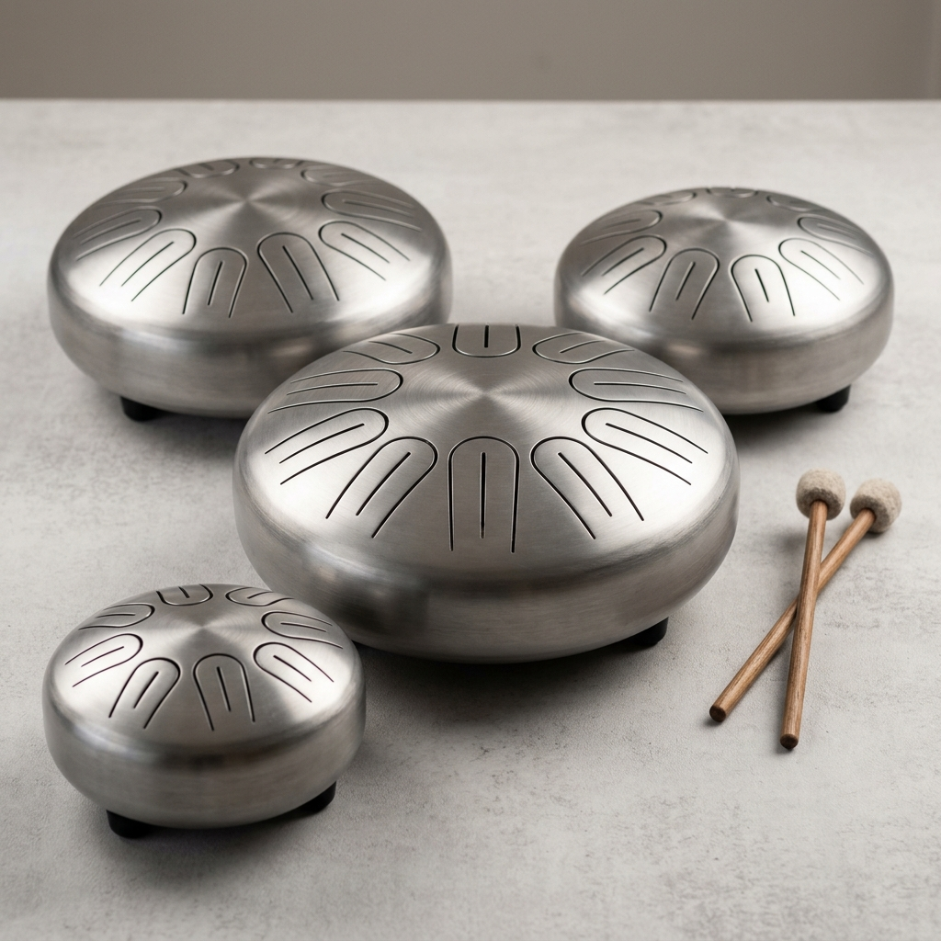
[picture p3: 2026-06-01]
images/family-group.png

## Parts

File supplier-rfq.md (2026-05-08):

# Supplier RFQ Draft

Subject: RFQ - steel tongue drum blank / cutting service

Hello,

I am preparing a prototype steel tongue drum and need either a steel shell/blank, cutting service, or both. The project is a struck musical instrument, so material consistency, low warp, clean edges, and documented kerf matter more than cosmetic speed.

## Requested Quote

- Quantity: 1 prototype, with option for 2-3 follow-up blanks.
- Material: low-carbon mild steel preferred for the first prototype.
- Thickness target: near 0.079 in; please quote actual available thickness and tolerance.
- Body target: 12 in diameter, 6 in high shell/vessel or compatible top/shell blank.
- Cutting: tongue slots and 2.5 in port from supplied DXF/SVG when finalized.
- Edge condition: quote as-cut condition, deburring options, and expected kerf/taper.
- Process options: waterjet, fiber laser, CO2 laser, CNC mill, or recommended alternative.

## Please Include

- Material grade and data sheet.
- Actual thickness tolerance.
- Cutting kerf estimate.
- Heat affected zone or warp expectations.
- Deburring/edge-finishing options.
- Unit price and lead time.
- Whether nested test coupons can be included for kerf and tuning trials.

Substitutions are acceptable only if the grade, thickness, cutting process, and expected edge condition are clearly identified.

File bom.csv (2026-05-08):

item_id | part_name | qty | unit | required_spec | estimated_cost | cost_basis | critical_to_tuning | notes
BOM-001 | Steel shell or formed blank | 1 | each | 12 in diameter by 6 in high steel vessel or equivalent blank; thickness near 0.079 in; low-carbon steel preferred for first prototype | 60 | rough planning estimate; verify before purchase | yes | Actual grade and thickness drive the first-pass K assumption.
BOM-002 | Top tongue field blank | 1 | each | Integral shell top or welded steel top compatible with 0.079 in tongue field | 35 | rough planning estimate; verify before purchase | yes | Avoid unknown hardened or heavily stressed salvage until measured.
BOM-003 | Rubber isolation feet | 3 | set | Low-profile rubber feet or grommet supports; non-rattling; mechanically isolated from tongues | 8 | rough planning estimate; verify before purchase | yes | Mounting can shift pitch and sustain.
BOM-004 | Mallet pair | 1 | pair | Medium-soft rubber or yarn-wrapped mallets; repeatable hardness for validation | 15 | rough planning estimate; verify before purchase | yes | Mallet hardness must be recorded in validation.
BOM-005 | Edge trim or rim protection | 1 | length | Non-rattling edge trim compatible with finish and hand contact | 12 | rough planning estimate; verify before purchase | no | Avoid added mass near tongues unless measured after install.
BOM-006 | Finish system | 1 | set | Corrosion-resistant finish or oil/wax compatible with struck instrument use | 18 | rough planning estimate; verify before purchase | yes | Finish mass and cure can move pitch.
BOM-007 | Abrasives and deburring tools | 1 | set | Files, deburring wheel, abrasive pad, fine abrasive sheets | 20 | rough planning estimate; verify before purchase | yes | Deburr must smooth without uncontrolled thinning.
BOM-008 | Tuning measurement tools | 1 | set | Chromatic tuner or spectrum app, microphone, calipers, notebook | 0 | shop-owned or verify before purchase | yes | Required for public-review readiness.

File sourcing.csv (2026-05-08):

item_id | part_name | required_spec | search_terms | candidate_sources | date_checked | unit_price | lead_time | substitution_policy | sourcing_risk
SRC-001 | Low-carbon steel shell | 12 in diameter by about 6 in high; thickness close to 0.079 in; weldable low-carbon steel | 12 inch steel hemisphere shell 14 gauge low carbon steel vessel blank | metal supplier, fabrication shop, online metal spinner | not checked | verify before purchase | verify before purchase | Substitute only after recalculating and measuring thickness | Unknown grade or forming stress changes tuning.
SRC-002 | Steel sheet/top blank | Flat or formed steel compatible with tongue cutting and shell attachment | 14 gauge mild steel sheet 0.075 0.080 low carbon | local metal supplier, OnlineMetals, McMaster search | not checked | verify before purchase | verify before purchase | Accept nearby gauge only with measured thickness update | Nominal gauge may differ from actual thickness.
SRC-003 | Cutting service | Laser, waterjet, or CNC service that can hold slot geometry and document kerf | waterjet steel tongue drum blank laser cutting mild steel 14 gauge | local waterjet shop, laser cutting shop, makerspace metal shop | not checked | quote required | quote required | Prefer waterjet when heat warp is unacceptable | Laser HAZ and waterjet taper both affect pitch.
SRC-004 | Rubber isolation feet | Soft non-rattling feet with screws or adhesive backing | rubber bumper feet instrument isolation grommet | hardware store, McMaster, Amazon search | not checked | verify before purchase | verify before purchase | Any equivalent that does not rattle | Mount stiffness affects sustain and pitch.
SRC-005 | Mallets | Medium-soft repeatable mallet pair | steel tongue drum mallets rubber yarn medium soft | music supplier, percussion supplier | not checked | verify before purchase | verify before purchase | Substitute only if hardness is logged | Hard mallets emphasize partials and can confuse tuner readings.
SRC-006 | Finish | Low-build corrosion protection compatible with hand contact | clear lacquer steel instrument finish paste wax corrosion protection | hardware store, finishing supplier | not checked | verify before purchase | verify before purchase | Avoid thick coatings until measured | Finish adds mass and can damp tongues.

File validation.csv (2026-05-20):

check_id | phase | tongue_or_feature | target_note | target_hz | measured_hz | cents_error | tolerance | environment | support_condition | mallet | process_state | result | action_notes
VAL-001 | formula sanity | A4 | A4 | 440.00 |  |  | 0 cents | shop temp logged at test | free support and final mount | validation mallet | pre-build | open | Confirm target formula returns A4 = 440 Hz.
VAL-002 | rough-cut | bass | D3 | 146.83 |  |  | record only | log temp/humidity | rough support | medium-soft | after slot cutting | open | Measure before deburr if safe; note cutter, kerf, HAZ, and warp.
VAL-003 | rough-cut | tongue 1 | A3 | 220.00 |  |  | record only | log temp/humidity | rough support | medium-soft | after slot cutting | open | Do not tune until burrs are controlled.
VAL-004 | deburr | all tongues | n/a |  |  |  | no sharp burrs; no uncontrolled thinning | shop | rough support | n/a | after deburr | open | Inspect both sides and root radius; photograph burr condition.
VAL-005 | first strike | bass | D3 | 146.83 |  |  | plus/minus 50 cents initial | log temp/humidity | consistent temporary isolation | medium-soft | deburr complete | open | Record first stable tuner reading and spectrum if available.
VAL-006 | first strike | tongue 1 | A3 | 220.00 |  |  | plus/minus 50 cents initial | log temp/humidity | consistent temporary isolation | medium-soft | deburr complete | open | Repeat for every tongue before material removal.
VAL-007 | tuning pass | all tongues | scale targets |  |  |  | final target plus/minus 10 cents before mount | log temp/humidity | consistent temporary isolation | medium-soft | incremental trim | open | Log every trim pass and whether pitch rose or fell.
VAL-008 | final mount | all tongues | scale targets |  |  |  | plus/minus 10 cents after mount | log temp/humidity | final feet/cradle | medium-soft | mounted | open | Compare mounted readings to temporary support readings.
VAL-009 | finish check | all tongues | scale targets |  |  |  | plus/minus 10 cents after finish cure | log temp/humidity | final feet/cradle | medium-soft | finish cured | open | Check damping and pitch shift after finish.
VAL-010 | drift check | all tongues | scale targets |  |  |  | plus/minus 10 cents after 24-72 h rest | log temp/humidity | final feet/cradle | medium-soft | rested | open | Public-review gate: update validation-report.md from measured data.
VAL-011 | structural check | slot roots | n/a |  |  |  | no visible cracks after tuning | shop | final support | n/a | post tuning | open | Inspect root radii under bright light.
VAL-012 | ergonomic check | playing surface | n/a |  |  |  | comfortable reach; no sharp edges | shop | final support | medium-soft | post assembly | open | Confirm player can strike all tongues without contacting sharp rim.
VAL-013 | CAM/CAD coupon gate | validation coupon | n/a |  |  |  | measured coupon kerf edge condition and compensation decision logged | shop | coupon fixture | medium-soft if strikeable | coupon complete | open | Populate data/coupon-cam-cad-log.csv before promoting DXF/CAM authority.
VAL-014 | CAM/CAD release | full tongue field | n/a |  |  |  | coupon evidence reviewed before full tongue-field export | shop | n/a | n/a | pre-release | open | Keep CAD/DXF/CAM as documentation-only until VAL-013 is complete and reviewed.

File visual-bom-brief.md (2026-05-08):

# Visual BOM Brief

## Goal

Create a one-page visual BOM that lets a fabricator or reviewer understand the steel tongue drum parts without reading every CSV.

## Layout

- Header: Steel Tongue Drum, STD-001, quote date, estimated total.
- Main image: top layout drawing from `drawings/steel-tongue-drum-layout.svg`.
- Row images: shell blank, tongue field, port, rubber feet, mallets, finish, deburring tools.
- Columns: item id, part, visual, quantity, required spec, cost basis, tuning risk.

## Required Labels

- "Derived estimate" for any tongue geometry.
- "Verify before purchase" for price and supplier information.
- "Measured data required" near tuning-critical parts.

## Shot Priority

Until real photos exist, use clean line drawings and explicit placeholders. Do not use atmospheric concept images as proof of manufactured geometry.

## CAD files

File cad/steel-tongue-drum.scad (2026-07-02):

// steel-tongue-drum.scad — parametric build-envelope + tongue-cut LAYOUT master
// ===========================================================================
// UNITS: inches (design table native). OpenSCAD units are generic.
//
// SOURCE OF TRUTH:
//   steel-tongue-drum-design-table.xlsx, design.md (Governing Model + Target
//   Tongue Table), family-spec.csv (STD-001: 12 in OD, 6 in H, 0.079 in steel,
//   11 tongues, 1 in tongue width, 2.5 in port).
//   Tongue free lengths are EQUATION-DRIVEN from target frequency:
//     L = sqrt(K_steel * t / f),  K_steel = 32098 (imperial), t = 0.079 in.
//
// AUTHORITY: pending_measurement. This is a build-ENVELOPE + tongue-cut-LAYOUT
//   master only. The tuning-sensitive geometry — actual kerf, slot-end
//   stress-relief radii, heat-affected zone, and the final tuned trim length of
//   every tongue — is HAND-REFINED from measured coupon + strike data and is
//   OUT OF SCOPE here (design.md Empirical Tuning Workflow; cnc coupon gate).
//   Do NOT export a tongue-field DXF/CAM cut file from this master until the
//   coupon gate (data/coupon-cam-cad-log.csv) and validation.csv are measured.
// ===========================================================================

// ---- Shell / vessel envelope (family-spec.csv STD-001) --------------------
body_diameter_in  = 12.0;   // body_diameter_in
shell_height_in   = 6.0;    // shell_height_in
steel_thickness_in= 0.079;  // steel_thickness_in (verify with calipers)
port_diameter_in  = 2.5;    // port_diameter_in
top_plate_in      = steel_thickness_in;

// ---- Tongue field (design.md Governing Model + Target Tongue Table) --------
K_steel           = 32098;  // workbook steel constant (imperial), first-pass
tongue_width_in   = 1.0;    // tongue_width, design table
tongue_root_inset = 0.6;    // radial inset of tongue root from rim (layout)
slot_kerf_in      = 0.040;  // kerf (process-dependent; coupon-verify)

// Tongue schedule: [label, target_Hz]  (design.md Target Tongue Table)
tongues = [
  ["D3",  146.83],  // bass
  ["A3",  220.00],
  ["Bb3", 233.08],
  ["C4",  261.63],
  ["D4",  293.66],
  ["E4",  329.63],
  ["F4",  349.23],
  ["G4",  392.00],
  ["A4",  440.00],
  ["C5",  523.25],
  ["D5",  587.33],
];
n_tongues = len(tongues);

// Equation-driven free tongue length (in) from target frequency (design.md).
function tongue_len_in(f) = sqrt(K_steel * steel_thickness_in / f);

$fn = 160;

// ---- Modules --------------------------------------------------------------
module shell() {
    R = body_diameter_in/2;
    // Closed-bottom cylindrical vessel with a side port.
    difference() {
        cylinder(h = shell_height_in, r = R);
        translate([0,0,top_plate_in])
            cylinder(h = shell_height_in, r = R - steel_thickness_in);
        // side sound port
        translate([0, -R-1, shell_height_in*0.35])
            rotate([-90,0,0]) cylinder(h = 2, r = port_diameter_in/2);
    }
}

module top_plate() {
    R = body_diameter_in/2;
    translate([0,0,shell_height_in - top_plate_in])
        cylinder(h = top_plate_in, r = R);
}

// One radial tongue-cut LAYOUT slot (U-outline), root near rim, tip inward.
// Length is equation-driven; this is layout, not a tuned cut.
module tongue_slot(f, angle_deg) {
    R = body_diameter_in/2;
    L = tongue_len_in(f);
    w = tongue_width_in;
    rotate([0,0,angle_deg])
        translate([0,0, shell_height_in - top_plate_in - 0.01])
            // U-shaped kerf around a radial tongue; open end at the root (rim side)
            difference() {
                // outer kerf footprint
                translate([R - tongue_root_inset - L - slot_kerf_in, -w/2 - slot_kerf_in, 0])
                    cube([L + slot_kerf_in, w + 2*slot_kerf_in, top_plate_in + 0.02]);
                // tongue body left uncut (attached at root, rim side)
                translate([R - tongue_root_inset - L, -w/2, -0.01])
                    cube([L + 0.02, w, top_plate_in + 0.04]);
            }
}

module tongue_field() {
    for (i = [0 : n_tongues-1])
        tongue_slot(tongues[i][1], i * 360/n_tongues);
}

// ---- Top-level assembly ---------------------------------------------------
module steel_tongue_drum() {
    shell();
    difference() {
        top_plate();
        tongue_field();   // cut the tongue-window LAYOUT into the top plate
    }
}

steel_tongue_drum();

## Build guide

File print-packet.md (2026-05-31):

# Steel Tongue Drum Capstone Print Packet

Generated: 2026-05-08
Packet folder: `/mnt/c/Users/Tony/Documents/GitHub/steel-tongue-drum`

## File Map

| File | Purpose |
| --- | --- |
| `design.md` | Project intent, catalog metadata, assumptions, and validation plan. |
| `bom.csv` | Starter bill of materials with part categories, quantities, drawing refs, and notes. |
| `sourcing.csv` | Supplier/search tracker with specs, price/date fields, lead time, substitutes, and risks. |
| `cut-list.csv` | Rough/final stock sizes, material, grain/orientation, operations, yield, and offcuts. |
| `drawing-brief.md` | Manufacturing drawing and technical product sketch brief. |
| `assembly-manual.md` | Shop-facing sequence, tools, fixtures, safety, tuning, finishing, and maintenance notes. |
| `validation.csv` | Target/measured values, tolerance, environment, result, and tuning/build action log. |
| `supplier-rfq.md` | Supplier email/request-for-quote starter. |
| `visual-bom-brief.md` | Art direction for an image-forward visual BOM. |
| `steel-tongue-drum-starter.wl` | Wolfram starter for physics, optimization, visualization, and validation. |
| `README.md` | Project artifact. |
| `family-spec.csv` | Project artifact. |
| `jig-decision.md` | Project artifact. |
| `photo-shotlist.md` | Project artifact. |
| `resources.md` | Project artifact. |
| `risks.md` | Project artifact. |
| `validation-report.md` | Project artifact. |

## design.md

Project intent, catalog metadata, assumptions, and validation plan.

# Steel Tongue Drum Design

Generated: 2026-05-08

## Intent

Create a traceable root-mode packet for a tuned steel tongue drum. The packet documents the first-pass geometry from `steel-tongue-drum-design-table.xlsx`, the manufacturing assumptions that can move pitch, and the validation workflow needed to turn estimates into a tuned instrument.

This design is intentionally conservative about claims. The workbook formulas size tongues from a cantilever model, but the final instrument must be tuned by measured cutting and strike tests.

## Source Artifacts

| Source | Role | Status |
| --- | --- | --- |
| `steel-tongue-drum-design-table.xlsx` | Design table and first-pass geometry | Present |
| `README.md` | Root repo overview | Expanded in this packet |
| `instrument-maker-v4` references | Physics, sourcing, print packet, validator | Applied |
| Measured prototype data | Required for final tuning confidence | Not present |

## Workbook Inputs Used

| Parameter | Value | Unit | Source / confidence |
| --- | ---: | --- | --- |
| Shell outside diameter | 12.000 | in | workbook input, assumption |
| Shell height | 6.000 | in | workbook input, assumption |
| Steel thickness | 0.079 | in | workbook input, verify with calipers |
| Kerf width | 0.040 | in | workbook input, process-dependent |
| Tongue count | 11 | count | workbook note rows include bass row plus 10 numbered rows |
| Tongue width | 1.000 | in | workbook input, derived estimate |
| Port diameter | 2.500 | in | workbook input, derived estimate |
| Tuning standard | 440 | Hz | A4 reference |
| Selected K constant | 32098 | imperial | workbook steel table, first-pass only |

## Governing Model

Use the cantilever beam model only as an initial layout estimate:

```text
f = K_steel * t / L^2
L = sqrt(K_steel * t / f)
```

Where:

- `f` is target frequency in Hz.
- `K_steel` is the workbook steel constant, currently 32098 for the selected steel row.
- `t` is steel thickness in inches.
- `L` is free tongue length in inches.

The model assumes an ideal fixed-free tongue. A real steel tongue drum departs from that ideal because the tongue remains part of a stressed plate/shell, is cut by a finite kerf, may be heat affected, may retain burrs, and is coupled to the vessel body and support system.

## Target Tongue Table

The values below are first-pass estimates from the workbook formula family. Treat every length as a starting cut length with trim allowance, not a final tuned dimension.

| Tongue | MIDI | Note | Target Hz | Derived length in | Derived length mm | Status |
| ---: | ---: | --- | ---: | ---: | ---: | --- |
| Bass | 50 | D3 | 146.83 | 4.16 | 105.6 | derived estimate |
| 1 | 57 | A3 | 220.00 | 3.39 | 86.2 | derived estimate |
| 2 | 58 | A#3/Bb3 | 233.08 | 3.30 | 83.7 | derived estimate |
| 3 | 60 | C4 | 261.63 | 3.11 | 79.0 | derived estimate |
| 4 | 62 | D4 | 293.66 | 2.94 | 74.6 | derived estimate |
| 5 | 64 | E4 | 329.63 | 2.77 | 70.4 | derived estimate |
| 6 | 65 | F4 | 349.23 | 2.69 | 68.4 | derived estimate |
| 7 | 67 | G4 | 392.00 | 2.54 | 64.5 | derived estimate |
| 8 | 69 | A4 | 440.00 | 2.40 | 60.9 | derived estimate |
| 9 | 72 | C5 | 523.25 | 2.20 | 55.9 | derived estimate |
| 10 | 74 | D5 | 587.33 | 2.08 | 52.8 | derived estimate |

## Shell / Helmholtz Estimate

The workbook includes a first-pass vessel estimate using a 12 in diameter, 6 in high partial volume assumption and a 2.5 in port. This is useful for checking whether the shell may reinforce or color the tongue field, but it should not be treated as a final resonator design.

For this packet, the shell resonance is documented as a support variable:

- Verify actual internal volume after forming, welding, or purchased shell selection.
- Measure the port diameter after deburring and finish.
- Compare struck tongue spectra mounted and unmounted.
- Record whether final mounting shifts pitch or sustain.

## Empirical Tuning Workflow

1. Rough-cut the tongues long or conservative, with rounded stress-relief termini.
2. Deburr both sides without thinning the root unpredictably.
3. Strike each tongue with the same mallet and support condition.
4. Log measured Hz and cents error in `validation.csv`.
5. Remove material in controlled passes, favoring tip/length correction first.
6. Re-measure after each tuning pass and after final mounting.
7. Re-check drift after finish cure and 24-72 hours of rest.

## Manufacturing Assumptions

- Steel grade is not locked. Mild low-carbon sheet is the default planning case; stainless is acceptable only after revisiting K, cutting method, corrosion plan, and work hardening behavior.
- Thickness must be measured at the actual blank, not assumed from nominal sheet gauge.
- Laser cutting is fast but risks heat affected zones and local stress changes.
- Waterjet cutting reduces heat risk but can leave taper, abrasive edge texture, and local burrs.
- CNC milling can control slot geometry but needs serious fixturing and coolant/chip planning on thin steel.
- Every inside slot end needs a smooth radius to reduce crack initiation.

## Unresolved Tuning Assumptions

- Actual steel grade, modulus, density, hardness, and residual stress.
- Actual kerf after the chosen cutting process.
- Whether the blank is flat sheet, preformed shell, salvaged vessel, or welded assembly.
- Final support/isolation scheme.
- Mallet hardness and strike point standard.
- Finish mass and corrosion-protection method.
- Whether the bass tongue and high tongues remain balanced in volume and sustain after final trimming.

## Acceptance Criteria

The packet becomes public-review ready only after:

- Each tongue has target Hz, measured Hz, cents error, mallet condition, support condition, and environment logged.
- Rough-cut, deburr, first strike, tuning pass, final mount, and drift check rows are complete.
- At least one process note records actual kerf, burr condition, and heat/warp observations.
- `validation-report.md` is updated from measured data rather than assumptions.

## bom.csv

Starter bill of materials with part categories, quantities, drawing refs, and notes.

| item_id | part_name | qty | unit | required_spec | estimated_cost | cost_basis | critical_to_tuning | notes |
| --- | --- | --- | --- | --- | --- | --- | --- | --- |
| BOM-001 | Steel shell or formed blank | 1 | each | 12 in diameter by 6 in high steel vessel or equivalent blank; thickness near 0.079 in; low-carbon steel preferred for first prototype | 60 | rough planning estimate; verify before purchase | yes | Actual grade and thickness drive the first-pass K assumption. |
| BOM-002 | Top tongue field blank | 1 | each | Integral shell top or welded steel top compatible with 0.079 in tongue field | 35 | rough planning estimate; verify before purchase | yes | Avoid unknown hardened or heavily stressed salvage until measured. |
| BOM-003 | Rubber isolation feet | 3 | set | Low-profile rubber feet or grommet supports; non-rattling; mechanically isolated from tongues | 8 | rough planning estimate; verify before purchase | yes | Mounting can shift pitch and sustain. |
| BOM-004 | Mallet pair | 1 | pair | Medium-soft rubber or yarn-wrapped mallets; repeatable hardness for validation | 15 | rough planning estimate; verify before purchase | yes | Mallet hardness must be recorded in validation. |
| BOM-005 | Edge trim or rim protection | 1 | length | Non-rattling edge trim compatible with finish and hand contact | 12 | rough planning estimate; verify before purchase | no | Avoid added mass near tongues unless measured after install. |
| BOM-006 | Finish system | 1 | set | Corrosion-resistant finish or oil/wax compatible with struck instrument use | 18 | rough planning estimate; verify before purchase | yes | Finish mass and cure can move pitch. |
| BOM-007 | Abrasives and deburring tools | 1 | set | Files, deburring wheel, abrasive pad, fine abrasive sheets | 20 | rough planning estimate; verify before purchase | yes | Deburr must smooth without uncontrolled thinning. |
| BOM-008 | Tuning measurement tools | 1 | set | Chromatic tuner or spectrum app, microphone, calipers, notebook | 0 | shop-owned or verify before purchase | yes | Required for public-review readiness. |

## sourcing.csv

Supplier/search tracker with specs, price/date fields, lead time, substitutes, and risks.

| item_id | part_name | required_spec | search_terms | candidate_sources | date_checked | unit_price | lead_time | substitution_policy | sourcing_risk |
| --- | --- | --- | --- | --- | --- | --- | --- | --- | --- |
| SRC-001 | Low-carbon steel shell | 12 in diameter by about 6 in high; thickness close to 0.079 in; weldable low-carbon steel | 12 inch steel hemisphere shell 14 gauge low carbon steel vessel blank | metal supplier, fabrication shop, online metal spinner | not checked | verify before purchase | verify before purchase | Substitute only after recalculating and measuring thickness | Unknown grade or forming stress changes tuning. |
| SRC-002 | Steel sheet/top blank | Flat or formed steel compatible with tongue cutting and shell attachment | 14 gauge mild steel sheet 0.075 0.080 low carbon | local metal supplier, OnlineMetals, McMaster search | not checked | verify before purchase | verify before purchase | Accept nearby gauge only with measured thickness update | Nominal gauge may differ from actual thickness. |
| SRC-003 | Cutting service | Laser, waterjet, or CNC service that can hold slot geometry and document kerf | waterjet steel tongue drum blank laser cutting mild steel 14 gauge | local waterjet shop, laser cutting shop, makerspace metal shop | not checked | quote required | quote required | Prefer waterjet when heat warp is unacceptable | Laser HAZ and waterjet taper both affect pitch. |
| SRC-004 | Rubber isolation feet | Soft non-rattling feet with screws or adhesive backing | rubber bumper feet instrument isolation grommet | hardware store, McMaster, Amazon search | not checked | verify before purchase | verify before purchase | Any equivalent that does not rattle | Mount stiffness affects sustain and pitch. |
| SRC-005 | Mallets | Medium-soft repeatable mallet pair | steel tongue drum mallets rubber yarn medium soft | music supplier, percussion supplier | not checked | verify before purchase | verify before purchase | Substitute only if hardness is logged | Hard mallets emphasize partials and can confuse tuner readings. |
| SRC-006 | Finish | Low-build corrosion protection compatible with hand contact | clear lacquer steel instrument finish paste wax corrosion protection | hardware store, finishing supplier | not checked | verify before purchase | verify before purchase | Avoid thick coatings until measured | Finish adds mass and can damp tongues. |

## cut-list.csv

Rough/final stock sizes, material, grain/orientation, operations, yield, and offcuts.

| cut_id | part_name | qty | material | rough_dimensions_in | final_dimensions_in | operation | datum | kerf_allowance_in | inspection |
| --- | --- | --- | --- | --- | --- | --- | --- | --- | --- |
| CUT-001 | Shell blank | 1 | low-carbon steel | 12.5 dia x 6.25 high planning envelope | 12.0 dia x 6.0 high target | source/form/trim shell | centerline and rim plane | 0.040 | Confirm roundness, thickness, and no oil-can flex. |
| CUT-002 | Port opening | 1 | same shell | pilot hole plus trim margin | 2.5 dia port | cut/deburr port | shell centerline | 0.040 | Measure actual diameter and edge smoothness. |
| CUT-003 | Bass tongue slot | 1 | 0.079 in steel top | layout from 4.16 in tongue length plus stress radius | derived estimate; tune by measurement | rough-cut slot | top centerline | 0.040 | Leave trim allowance; log first-strike Hz. |
| CUT-004 | Tongue 1 slot | 1 | 0.079 in steel top | layout from 3.39 in tongue length plus stress radius | derived estimate; tune by measurement | rough-cut slot | top centerline | 0.040 | Deburr before first measured strike. |
| CUT-005 | Tongue 2 slot | 1 | 0.079 in steel top | layout from 3.30 in tongue length plus stress radius | derived estimate; tune by measurement | rough-cut slot | top centerline | 0.040 | Check kerf and root radius. |
| CUT-006 | Tongue 3 slot | 1 | 0.079 in steel top | layout from 3.11 in tongue length plus stress radius | derived estimate; tune by measurement | rough-cut slot | top centerline | 0.040 | Check for heat warp before tuning. |
| CUT-007 | Tongue 4 slot | 1 | 0.079 in steel top | layout from 2.94 in tongue length plus stress radius | derived estimate; tune by measurement | rough-cut slot | top centerline | 0.040 | Measure Hz before material removal. |
| CUT-008 | Tongue 5 slot | 1 | 0.079 in steel top | layout from 2.77 in tongue length plus stress radius | derived estimate; tune by measurement | rough-cut slot | top centerline | 0.040 | Tune in small passes. |
| CUT-009 | Tongue 6 slot | 1 | 0.079 in steel top | layout from 2.69 in tongue length plus stress radius | derived estimate; tune by measurement | rough-cut slot | top centerline | 0.040 | Watch for burr mass and damping. |
| CUT-010 | Tongue 7 slot | 1 | 0.079 in steel top | layout from 2.54 in tongue length plus stress radius | derived estimate; tune by measurement | rough-cut slot | top centerline | 0.040 | Check sustain versus adjacent tongues. |
| CUT-011 | Tongue 8 slot | 1 | 0.079 in steel top | layout from 2.40 in tongue length plus stress radius | derived estimate; tune by measurement | rough-cut slot | top centerline | 0.040 | A4 formula sanity row. |
| CUT-012 | Tongue 9 slot | 1 | 0.079 in steel top | layout from 2.20 in tongue length plus stress radius | derived estimate; tune by measurement | rough-cut slot | top centerline | 0.040 | High tongues may be quiet; verify volume. |
| CUT-013 | Tongue 10 slot | 1 | 0.079 in steel top | layout from 2.08 in tongue length plus stress radius | derived estimate; tune by measurement | rough-cut slot | top centerline | 0.040 | Avoid over-thinning short tongue roots. |
| CUT-014 | Fixture ring or cradle | 1 | MDF plywood or printed fixture | 14 x 14 x 0.75 planning blank | cradle fits shell without rocking | cut jig | rim plane | 0.000 | Must hold shell without damping tongue field. |

## drawing-brief.md

Manufacturing drawing and technical product sketch brief.

# Drawing Brief

## Required Drawing Set

1. Top layout with all tongue slots, centerline, port, rim, and orientation mark.
2. Section view through shell showing top thickness, shell height, port, support feet, and rim/edge treatment.
3. Detail view of a tongue root with slot-end radius, kerf, burr limit, and stress-relief note.
4. Fixture view showing temporary tuning support and final isolation feet.
5. Process coupon drawing for kerf and HAZ validation.

## Critical Dimensions

- 12.0 in body diameter assumption.
- 6.0 in shell height assumption.
- 0.079 in steel thickness assumption.
- 0.040 in kerf assumption.
- 1.0 in tongue width assumption.
- 2.5 in port diameter assumption.
- Tongue lengths from `design.md` are derived estimates and must be marked "rough-cut; tune by measurement."

## Drawing Rules

- Units: inches with metric equivalents where useful.
- Include title block, revision, date, material, finish, and "not final tuned dimensions" note.
- Show datum A as top center, datum B as rim plane, datum C as orientation line.
- Call out all inside slot ends as smooth radiused transitions.
- Do not publish as final manufacturing drawing until validation data exists.

## assembly-manual.md

Shop-facing sequence, tools, fixtures, safety, tuning, finishing, and maintenance notes.

# Assembly Manual

## Safety

Steel cutting, deburring, and tuning can create sharp edges, hot work, abrasive dust, and springy tongues. Wear eye protection, gloves when handling raw cuts, and hearing protection during cutting or repeated striking. Do not strike an unfinished blank with sharp burrs in a way that can throw chips.

## Tools

- Calipers and steel rule.
- Layout template or CAD print.
- Cutting process: waterjet, laser, CNC mill, or carefully controlled manual process.
- Deburring tools, small files, abrasive pads, and inspection light.
- Tuner or spectrum analyzer with repeatable microphone placement.
- Medium-soft mallets reserved for validation.
- Temporary support cradle and final isolation feet.

## Build Sequence

1. Confirm the actual steel grade, thickness, shell diameter, shell height, and port diameter.
2. Update the workbook or `design.md` assumptions if measured thickness differs from 0.079 in.
3. Mark the top centerline, tongue layout, port, and any logo or orientation mark.
4. Cut the port first if it helps workholding; deburr and record actual diameter.
5. Rough-cut tongue slots using rounded slot ends and the documented kerf.
6. Inspect for heat discoloration, slot taper, burrs, and oil-can distortion.
7. Deburr both sides, preserving root radius and avoiding uncontrolled thinning.
8. Place the drum on a temporary isolation support and record first-strike measurements.
9. Tune iteratively, one tongue at a time, recording measured Hz and cents error.
10. Install final feet, edge trim, and finish only after pre-finish tuning is documented.
11. Re-check pitch after final mounting, after finish cure, and after a 24-72 hour drift rest.

## Tuning Notes

For this first prototype, do not chase a perfect tuner reading from one strike. Use the same mallet, strike point, support, and microphone distance. Record at least three stable readings per tongue where possible.

If a tongue is sharp after rough cutting, lower pitch by increasing effective length or removing material in a way that reduces stiffness. If a tongue is flat, options are limited; shorten the effective tongue or accept a revised target. This is why rough-cut length should stay conservative.

## Photo Checkpoints

- Raw shell and thickness measurement.
- Layout before cutting.
- Slot kerf sample coupon.
- Rough-cut top before deburr.
- Deburred tongue roots.
- First-strike measurement setup.
- Tuning pass with tool marks visible.
- Final mount and underside/support detail.

## validation.csv

Target/measured values, tolerance, environment, result, and tuning/build action log.

| check_id | phase | tongue_or_feature | target_note | target_hz | measured_hz | cents_error | tolerance | environment | support_condition | mallet | process_state | result | action_notes |
| --- | --- | --- | --- | --- | --- | --- | --- | --- | --- | --- | --- | --- | --- |
| VAL-001 | formula sanity | A4 | A4 | 440.00 |  |  | 0 cents | shop temp logged at test | free support and final mount | validation mallet | pre-build | open | Confirm target formula returns A4 = 440 Hz. |
| VAL-002 | rough-cut | bass | D3 | 146.83 |  |  | record only | log temp/humidity | rough support | medium-soft | after slot cutting | open | Measure before deburr if safe; note cutter, kerf, HAZ, and warp. |
| VAL-003 | rough-cut | tongue 1 | A3 | 220.00 |  |  | record only | log temp/humidity | rough support | medium-soft | after slot cutting | open | Do not tune until burrs are controlled. |
| VAL-004 | deburr | all tongues | n/a |  |  |  | no sharp burrs; no uncontrolled thinning | shop | rough support | n/a | after deburr | open | Inspect both sides and root radius; photograph burr condition. |
| VAL-005 | first strike | bass | D3 | 146.83 |  |  | plus/minus 50 cents initial | log temp/humidity | consistent temporary isolation | medium-soft | deburr complete | open | Record first stable tuner reading and spectrum if available. |
| VAL-006 | first strike | tongue 1 | A3 | 220.00 |  |  | plus/minus 50 cents initial | log temp/humidity | consistent temporary isolation | medium-soft | deburr complete | open | Repeat for every tongue before material removal. |
| VAL-007 | tuning pass | all tongues | scale targets |  |  |  | final target plus/minus 10 cents before mount | log temp/humidity | consistent temporary isolation | medium-soft | incremental trim | open | Log every trim pass and whether pitch rose or fell. |
| VAL-008 | final mount | all tongues | scale targets |  |  |  | plus/minus 10 cents after mount | log temp/humidity | final feet/cradle | medium-soft | mounted | open | Compare mounted readings to temporary support readings. |
| VAL-009 | finish check | all tongues | scale targets |  |  |  | plus/minus 10 cents after finish cure | log temp/humidity | final feet/cradle | medium-soft | finish cured | open | Check damping and pitch shift after finish. |
| VAL-010 | drift check | all tongues | scale targets |  |  |  | plus/minus 10 cents after 24-72 h rest | log temp/humidity | final feet/cradle | medium-soft | rested | open | Public-review gate: update validation-report.md from measured data. |
| VAL-011 | structural check | slot roots | n/a |  |  |  | no visible cracks after tuning | shop | final support | n/a | post tuning | open | Inspect root radii under bright light. |
| VAL-012 | ergonomic check | playing surface | n/a |  |  |  | comfortable reach; no sharp edges | shop | final support | medium-soft | post assembly | open | Confirm player can strike all tongues without contacting sharp rim. |

## supplier-rfq.md

Supplier email/request-for-quote starter.

# Supplier RFQ Draft

Subject: RFQ - steel tongue drum blank / cutting service

Hello,

I am preparing a prototype steel tongue drum and need either a steel shell/blank, cutting service, or both. The project is a struck musical instrument, so material consistency, low warp, clean edges, and documented kerf matter more than cosmetic speed.

## Requested Quote

- Quantity: 1 prototype, with option for 2-3 follow-up blanks.
- Material: low-carbon mild steel preferred for the first prototype.
- Thickness target: near 0.079 in; please quote actual available thickness and tolerance.
- Body target: 12 in diameter, 6 in high shell/vessel or compatible top/shell blank.
- Cutting: tongue slots and 2.5 in port from supplied DXF/SVG when finalized.
- Edge condition: quote as-cut condition, deburring options, and expected kerf/taper.
- Process options: waterjet, fiber laser, CO2 laser, CNC mill, or recommended alternative.

## Please Include

- Material grade and data sheet.
- Actual thickness tolerance.
- Cutting kerf estimate.
- Heat affected zone or warp expectations.
- Deburring/edge-finishing options.
- Unit price and lead time.
- Whether nested test coupons can be included for kerf and tuning trials.

Substitutions are acceptable only if the grade, thickness, cutting process, and expected edge condition are clearly identified.

## visual-bom-brief.md

Art direction for an image-forward visual BOM.

# Visual BOM Brief

## Goal

Create a one-page visual BOM that lets a fabricator or reviewer understand the steel tongue drum parts without reading every CSV.

## Layout

- Header: Steel Tongue Drum, STD-001, quote date, estimated total.
- Main image: top layout drawing from `drawings/steel-tongue-drum-layout.svg`.
- Row images: shell blank, tongue field, port, rubber feet, mallets, finish, deburring tools.
- Columns: item id, part, visual, quantity, required spec, cost basis, tuning risk.

## Required Labels

- "Derived estimate" for any tongue geometry.
- "Verify before purchase" for price and supplier information.
- "Measured data required" near tuning-critical parts.

## Shot Priority

Until real photos exist, use clean line drawings and explicit placeholders. Do not use atmospheric concept images as proof of manufactured geometry.

## steel-tongue-drum-starter.wl

Wolfram starter for physics, optimization, visualization, and validation.

```wolfram
(* Steel Tongue Drum Wolfram starter *)

ClearAll["Global`*"];

(* Inputs from steel-tongue-drum-design-table.xlsx *)
bodyDiameterIn = 12.0;
shellHeightIn = 6.0;
steelThicknessIn = 0.079;
kerfIn = 0.040;
tongueWidthIn = 1.0;
portDiameterIn = 2.5;
a4Hz = 440.0;
kSteel = 32098.0;

targetMidis = <|
  "Bass" -> 50,
  "T1" -> 57,
  "T2" -> 58,
  "T3" -> 60,
  "T4" -> 62,
  "T5" -> 64,
  "T6" -> 65,
  "T7" -> 67,
  "T8" -> 69,
  "T9" -> 72,
  "T10" -> 74
|>;

midiToHz[m_] := a4Hz*2^((m - 69)/12);
tongueLengthIn[f_] := Sqrt[kSteel*steelThicknessIn/f];
centsError[measured_, target_] := 1200*Log2[measured/target];

targetTable = KeyValueMap[
  {#1, #2, midiToHz[#2], tongueLengthIn[midiToHz[#2]], 25.4*tongueLengthIn[midiToHz[#2]]} &,
  targetMidis
];

Grid[
  Prepend[targetTable, {"Tongue", "MIDI", "Target Hz", "Length in", "Length mm"}],
  Frame -> All
]

(* Validation example: replace with measured data from validation.csv. *)
measuredExampleHz = <|"T8" -> 440.0|>;
KeyValueMap[{#1, centsError[#2, midiToHz[targetMidis[#1]]]} &, measuredExampleHz]

(* Simple sensitivity plot: pitch versus tongue length for the selected steel thickness. *)
Plot[kSteel*steelThicknessIn/l^2, {l, 2.0, 4.5},
  AxesLabel -> {"Tongue length (in)", "Frequency (Hz)"},
  PlotLabel -> "First-pass cantilever estimate only"
]
```

## README.md

Project artifact.

# Steel Tongue Drum

Root-mode engineering packet for a tuned steel tongue drum: a slit-tongue steel idiophone whose final tuning must be measured and corrected on the actual prototype.

This repo is part of the [tonykoop/instrument-maker](https://github.com/tonykoop/instrument-maker) catalogue and uses the `instrument-maker-v4` root packet shape.

## What this is

This packet turns the existing `steel-tongue-drum-design-table.xlsx` into a build-ready documentation set for a circular steel tongue drum. The workbook provides first-pass geometry, material constants, target MIDI notes, a rough Helmholtz body estimate, and tongue length formulas.

The important caveat: steel tongue drums are empirical instruments. The cantilever equation is useful for rough layout, but final pitch depends on steel batch, residual stress, slot kerf, heat affected zone, burrs, mounting isolation, mallet hardness, finish mass, and the way each tongue is trimmed. This repo is therefore not "tuned" until measured prototype data exists in `validation.csv`.

## Current design baseline

| Item | Baseline |
| --- | --- |
| Body form | Round steel shell / vessel |
| Outside diameter | 12 in assumption from workbook |
| Shell height | 6 in assumption from workbook |
| Steel thickness | 0.079 in derived from workbook input |
| Slot kerf | 0.040 in workbook assumption |
| Tongue width | 1.0 in workbook assumption |
| Port diameter | 2.5 in workbook assumption |
| Tuning reference | A4 = 440 Hz |
| Governing model | `f = K_steel * t / L^2`, first-pass only |
| Validation state | No measured prototype data yet |

## Packet map

- `design.md` - design intent, assumptions, formulas, tuning workflow.
- `family-spec.csv` - root-mode family row for the current steel tongue drum.
- `bom.csv`, `sourcing.csv`, `cut-list.csv` - purchasing and shop prep.
- `assembly-manual.md` - rough build, cutting, tuning, finish, and mount steps.
- `validation.csv` - tuning and process validation rows, including rough-cut, deburr, first strike, tuning pass, final mount, and drift check.
- `drawing-brief.md`, `drawings/` - drawing requirements and starter layout SVG.
- `cad/`, `cnc/`, `jigs/` - SolidWorks/CAM/fixture briefs.
- `risks.md` - acoustic, structural, ergonomic, supply, and finish risks with tests.
- `capstone-deck.md`, `print-packet.md`, `print-packet.html`, `site/index.html` - review and presentation layers.

## Readiness

This packet is private-prototype ready. It should stay private for public technical review until a rough-cut prototype is struck, tuned, mounted, drift-checked, and logged with measured Hz and cents error.

## License

[CC BY 4.0](LICENSE) - see LICENSE for details.

## family-spec.csv

Project artifact.

| family_id | member_id | instrument_name | variant | key_or_scale | body_diameter_in | shell_height_in | steel_thickness_in | tongue_count | port_diameter_in | design_stage | validation_state | notes |
| --- | --- | --- | --- | --- | --- | --- | --- | --- | --- | --- | --- | --- |
| STD-FAM-001 | STD-001 | Steel Tongue Drum | 12 inch root prototype | D-centered mixed pentatonic/diatonic study | 12.0 | 6.0 | 0.079 | 11 | 2.5 | root-mode packet | no measured prototype data | Derived from steel-tongue-drum-design-table.xlsx; final tuning empirical. |

## jig-decision.md

Project artifact.

# Jig Decision

## Decision

Use a two-stage jig approach:

1. A non-marring temporary tuning cradle that supports the shell consistently while leaving the tongue field free.
2. A final isolation-foot layout that is re-measured after installation.

## Why

The support condition is part of the instrument. A rigid clamp, bench pad, hand hold, rubber foot, and display stand can all change damping and perceived pitch. Separating the temporary tuning cradle from the final mount makes that shift visible in `validation.csv`.

## Requirements

- Cradle must locate the shell repeatably without contacting vibrating tongues.
- Contact points should be soft enough to prevent rattles but stable enough for repeatable measurements.
- Fixture should expose the port and underside for inspection.
- Final feet must be installed before the final-mount validation phase.

## Rejected Options

- Freehand holding during tuning: too variable.
- Clamping the shell rigidly to a bench: likely to damp shell modes.
- Tuning only after final finish: hides process causes and makes correction harder.

## photo-shotlist.md

Project artifact.

# Photo Shotlist

- Raw steel shell or blank with label/spec visible.
- Caliper reading of actual steel thickness.
- Layout on top surface before cutting.
- Kerf coupon or test cut close-up.
- Rough-cut slots before deburring.
- Deburred slot root close-up with light showing radius.
- Temporary tuning support setup.
- Tuner/microphone placement during first strike.
- Tuning pass in progress with tool and tongue identified.
- Final feet or isolation mount underside.
- Finished top view with all tongues visible.
- Detail of port, rim, and edge trim.

## resources.md

Project artifact.

# Resources

## Local Packet Sources

- `steel-tongue-drum-design-table.xlsx` - workbook source for dimensions, K constants, target notes, and formulas.
- `design.md` - narrative design basis and assumptions.
- `validation.csv` - required measurement log.
- `drawings/steel-tongue-drum-layout.svg` - starter layout drawing.

## Instrument Maker References

- `instrument-maker-v4/references/new-instruments-v4.md` - steel tongue drum entry.
- `instrument-maker-v4/references/acoustic-models.md` - cantilever beam formulas and guard rules.
- `instrument-maker-v4/references/manufacturing-and-cnc.md` - machining and fixture guidance.
- `instrument-maker-v4/references/sourcing-and-production.md` - sourcing, RFQ, cut list, validation guidance.

## Sister Repos

- `tongue-drum` - wooden slit tongue drum done-bar reference and DoE pattern.
- `glockenspiel` - metal bar idiophone sibling concept.
- `handpan` - steel shell idiophone sibling, but different governing model.

## Measurement Tools To Use

- Chromatic tuner or spectral analysis app.
- Calipers for thickness, kerf, port, and slot checks.
- Consistent microphone placement.
- Temperature/humidity record for each tuning session.

## risks.md

Project artifact.

# Risks

## Acoustic

| Risk | Why it matters | Verification test |
| --- | --- | --- |
| Cantilever model over-promises accuracy | Real tongues are cut from a coupled steel shell, not ideal beams | First-strike each tongue and log cents error before tuning |
| Mallet hardness changes apparent pitch and partial balance | Hard mallets excite noisy partials and can confuse readings | Record mallet type; compare soft vs medium mallet on two tongues |
| Support condition shifts sustain and pitch | Feet/cradle can damp the shell or tongue roots | Measure before and after final mount |

## Structural

| Risk | Why it matters | Verification test |
| --- | --- | --- |
| Slot roots crack | Sharp inside corners concentrate stress | Inspect radiused roots after tuning and after drift check |
| Heat warp from cutting | Warped top changes stiffness and strike height | Photograph and straightedge-check before deburr |
| Over-tuning weakens short tongues | Removing too much material can make tongues unstable | Log every material-removal pass and stop if sustain collapses |

## Ergonomic

| Risk | Why it matters | Verification test |
| --- | --- | --- |
| Edge remains sharp | Player contact with rim and port is likely | Glove-off touch test only after full deburr |
| Tongue spacing is cramped | Adjacent tongues may be struck accidentally | Play-test simple scale pattern with final mallets |

## Supply

| Risk | Why it matters | Verification test |
| --- | --- | --- |
| Unknown steel grade | K and tuning response vary by material | Record grade/data sheet or mark as unknown in validation |
| Nominal sheet gauge differs from actual | Thickness enters the formula linearly | Caliper thickness at multiple points |

## Fit / Finish

| Risk | Why it matters | Verification test |
| --- | --- | --- |
| Finish adds damping or mass | Pitch and sustain can drift after coating | Measure before finish, after cure, and after drift rest |
| Feet or trim rattle | Rattles mask tuning and reduce quality | Strike every tongue at playing volume after final assembly |

## validation-report.md

Project artifact.

# Validation Report

## Current Status

No measured prototype data is present yet. The packet is documentation-complete enough to guide a prototype, but it is not public-review ready as a tuned instrument.

## What Has Been Validated

- A4 reference and equal-temperament target method are documented.
- Workbook assumptions have been surfaced in `design.md`.
- The required validation workflow exists in `validation.csv`.
- Manufacturing risks for laser, waterjet, CNC, deburring, support, finish, and drift are documented.

## What Remains Open

- Actual steel grade and thickness.
- Actual cutting kerf and edge condition.
- First-strike Hz for every tongue.
- Cents error before and after tuning.
- Pitch shift after final mounting.
- Pitch drift after finish cure and rest.

## Readiness Call

Private-prototype ready: yes.

Public-review ready: no. Keep the repo private or clearly marked as unvalidated until measured rough-cut, deburr, first-strike, tuning-pass, final-mount, and drift-check data exists.

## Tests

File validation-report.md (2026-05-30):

# Validation Report

**Status:** pre-build validation path is defined; no measured prototype data has been logged yet.

## Current result

The packet is ready for human shop review and first-prototype planning. All tongue lengths, target notes, and shell assumptions are still predictions from the workbook and first-order models. No row in `validation.csv` should be treated as measured performance until the `measured_hz`, `cents_error`, `environment`, `support_condition`, and `result` fields are populated from a real build.

## Prototype under test

| Field | Value |
|---|---|
| Member | STD-001 |
| Form | 12 in round steel shell / vessel |
| Scale study | D3 bass plus 10 upper tongues from the workbook layout |
| Material assumption | Low-carbon steel around 0.079 in thick |
| Port assumption | 2.5 in |
| Validation state | Planning packet only; no rough-cut prototype measured |

## What has been validated

- A4 reference and equal-temperament target method are documented.
- Workbook assumptions and first-pass tongue lengths are surfaced in `design.md`.
- The required tuning workflow exists in `validation.csv`.
- Manufacturing risks for laser, waterjet, CNC, deburring, support, finish, and drift are documented.
- `cnc/README.md`, `jig-decision.md`, and `data/measurement-capture-plan.md` define the coupon, support, and evidence path before any public tuning claims.
- `cnc/coupon-first-cam-cad-gate.md` and `data/coupon-cam-cad-log.csv` now define the issue #5 CAM/CAD promotion gate and evidence row.

## Physical measurements still needed

| Category | Required measurement | Why it matters |
|---|---|---|
| Material | Actual steel grade, thickness, and any forming/weld notes | The cantilever estimate depends directly on thickness and indirectly on real material behavior |
| Cutting | Actual kerf, taper, burr condition, HAZ, and top warp | Process artifacts can move pitch before any tuning begins |
| Rough-cut tuning | First-strike Hz for every tongue before trimming | Establishes how far the workbook estimate is from reality |
| Tuning path | Cents error and trim notes at each pass | Needed to prove the process is repeatable rather than lucky |
| Mounting | Temporary cradle vs final-feet pitch and sustain shift | Support condition is part of the instrument |
| Finish | Post-finish pitch shift and damping change | Coating mass can move tuning and sustain |
| Drift | 24-72 hour rest re-check | Confirms the result is stable enough for public review |

## Acceptance gates

| Gate | Target | Pass condition | Current state |
|---|---|---|---|
| Material confirmation | Real blank documented | Grade/spec recorded or explicitly marked unknown; thickness measured at multiple points | Pending build |
| Kerf coupon | First-process sample | Actual slot width and burr condition logged before cutting the instrument | Pending build |
| CAM/CAD release | Coupon-first authority | Coupon log records kerf, edge condition, and compensation decision before DXF/CAM promotion | Blocked until coupon evidence |
| Rough-cut first strike | Every tongue measured | Stable Hz captured for bass plus all numbered tongues | Pending build |
| Tuning pass | Pre-mount tuning | Each tongue within plus/minus 10 cents before final mount, or deviation explained | Pending build |
| Final mount | Mount-dependent shift documented | Temporary support vs final feet comparison recorded | Pending build |
| Finish check | Coating effect documented | Pitch and sustain re-checked after finish cure | Pending build |
| Drift check | Short-term stability | 24-72 hour rest reading logged | Pending build |
| Structural review | No cracks or unsafe edges | Slot roots intact, edges deburred, no rattles from feet or trim | Pending build |

## Test sequence

1. Measure the real blank thickness at multiple points and note the best available steel spec.
2. Cut and strike a kerf/tuning coupon using the actual process before cutting the full tongue field.
3. Document slot taper, burr condition, any HAZ or warp, and the CAM compensation decision in `data/coupon-cam-cad-log.csv`.
4. Rough-cut the full tongue field and capture first-strike Hz for every tongue on the temporary cradle.
5. Tune iteratively, logging every trim pass and cents change in `validation.csv`.
6. Install final feet or isolation supports and re-measure the full tongue set.
7. Apply finish only after pre-finish tuning is documented, then re-check after cure.
8. Run the 24-72 hour drift check and update this report from assumptions to measured results.

## Readiness call

Private-prototype ready: yes.

Public-review ready as a tuned instrument: no.

Issue #5 structure close-ready: yes, for the coupon-first CAM/CAD authority
surface only.

Public build-packet ready: no. The current packet remains an L2 V5 candidate
with pending measurement authority, not a tuned or fabrication-ready release.

CAM/CAD build-ready: no. The issue #5 coupon gate remains blocked until a real
coupon row is measured and reviewed.

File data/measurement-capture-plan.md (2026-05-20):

# Measurement Capture Plan

This file defines the minimum physical evidence needed before the steel tongue drum should be described as tuned or public-review ready.

## 1. Material confirmation

- Record supplier, part description, and best-available steel grade.
- Measure thickness at multiple points on the real blank.
- Note whether the build uses flat sheet, a preformed shell, a welded assembly, or salvage.

## 2. Cutting-process coupon

- Cut a coupon with the same process intended for the instrument.
- Record actual kerf width at several points.
- Photograph taper, burrs, discoloration, and any warp.
- Strike the coupon before and after deburring if the coupon geometry supports it.
- Record the CAM/CAD promotion decision in `data/coupon-cam-cad-log.csv`.

## 3. Rough-cut first strike

- Capture first stable Hz for bass plus every numbered tongue.
- Keep the support condition, mallet, and microphone placement fixed.
- Log any tongue that is already sharp or unexpectedly quiet before tuning starts.

## 4. Tuning passes

- Record each material-removal pass and whether it changed pitch as expected.
- Log cents error before and after the pass.
- Note any tongue that becomes weak, rattly, or structurally suspect.

## 5. Mount and finish checks

- Compare temporary cradle readings to final-foot readings.
- Measure again after finish cure.
- Re-check after 24-72 hours of rest for drift.

## 6. Evidence bundle

Minimum evidence for a public-safe tuning claim:

- populated `validation.csv`
- updated `validation-report.md`
- process notes or photos for material, coupon, and first-strike stages
- populated `data/coupon-cam-cad-log.csv` row for the coupon-first CAM/CAD gate
- explicit note of any remaining unknowns or revisions to the workbook assumptions

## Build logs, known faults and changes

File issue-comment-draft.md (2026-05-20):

# Issue Comment Draft

Draft for `tonykoop/steel-tongue-drum#1` only. Do not post automatically.

Round 2 sprint update:

The local `steel-tongue-drum` repo now has a stronger public-safe build-packet path. The packet is close-ready as documentation, but it is still intentionally not claiming a measured, finalized tuned instrument.

Current packet shape:

- root-mode packet docs present: `design.md`, `assembly-manual.md`, BOM, sourcing, cut list, validation, RFQ, visual BOM, drawing brief
- public-safe tuning and readiness language strengthened in `README.md` and `validation-report.md`
- manufacturing release path clarified in `cnc/README.md`, `jig-decision.md`, and `data/measurement-capture-plan.md`
- starter folders/docs present for `images/`, `data/`, and `wolfram/`
- drawings, build-log site, capstone materials, and print packet are present
- all current tuning values remain explicitly marked as predictions or assumptions until measured data exists

Validation run:

```bash
git -C /mnt/c/Users/Tony/Documents/GitHub/steel-tongue-drum status --short
python3 /mnt/c/Users/Tony/Documents/GitHub/instrument-maker/skills/v4/instrument-maker-v4/scripts/validate_packet.py /mnt/c/Users/Tony/Documents/GitHub/steel-tongue-drum --mode root --json
```

Validator result: `ok: true`, 0 findings.

Remaining assumptions / blockers before closing after human review:

- no measured prototype data exists yet for first-strike, tuning-pass, final-mount, finish-cure, or drift-check stages
- actual steel grade, actual thickness, actual kerf, burr condition, and mount-dependent pitch shift still need to be measured on the real build
- no build-ready CAM or final tuned CAD should be claimed until the coupon-first process in `cnc/README.md`, `cnc/coupon-first-cam-cad-gate.md`, `data/measurement-capture-plan.md`, and `data/coupon-cam-cad-log.csv` is completed
- real process photos should replace starter placeholders before public showcase use

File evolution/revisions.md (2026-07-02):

# Revision Register — steel-tongue-drum

| Rev | Date | Parent | Delta | Downstream artifacts invalidated |
| --- | --- | --- | --- | --- |
| A | 2026-07-01 | — | Stage 0 intake of current masters (cad/steel-tongue-drum.scad + steel-tongue-drum-design-table.xlsx + wolfram source). | none (no alpha/beta/production artifacts exist yet) |

Stage 0 only. Gate A has not been run; no Alpha compiles, vendor quotes, or production lock exist for this product.

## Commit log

2026-05-02 Initial scaffold: Steel Tongue Drum
    [steel-tongue-drum-design-table.xlsx]
2026-05-18 feat(learn-to-play): add steel-tongue-drum starter songbook (#3)
    * feat(learn-to-play): add steel-tongue-drum starter songbook (R4 claude-dan)
    Drop learn-to-play/ with 00-INDEX.md, scales/, fingerings/, and
    5 tunes (ABC + LilyPond + songsheet + notes). All tunes are
    public-domain traditional arrangements or original Heifer Zephyr
    compositions (MIT). Notation is at concert pitch; no external
    rendering tools required to read the ABC files.
    * fix: strip trailing whitespace from learn-to-play markdown files
    ---------
2026-05-18 Add steel tongue drum V5 explorer (#4)
    [visual-output-register.csv]
2026-05-20 Add steel tongue drum coupon CAM/CAD gate (#6)
    [coupon-cam-cad-log.csv, validation.csv, visual-output-register.csv]
2026-05-30 v5(steel-tongue-drum): honest packet surface (Refs #5) (#7)
    [visual-output-register.csv]
2026-05-31 Add image-gen concept prompt; wire explorer images
2026-05-31 Add deployable Wolfram interactive model + wire live explorer embed
    Model returns a bare Manipulate (SaveDefinitions->True); CloudDeploy'd Public.
2026-06-21 Wire 3 rendered concept image(s) into explorer gallery
2026-07-02 V5 packet refresh: status line, provenance, parametric OpenSCAD master, evolution intake
    - Authored cad/steel-tongue-drum.scad parametric build-envelope + tongue-cut
    LAYOUT master (equation-driven L=sqrt(32098*t/f)); openscad render exit 0.
    - Added CAD + Wolfram-model register rows and provenance session-log rows
    (Wolfram model existed from epic197 but had no register row).
    - evolution/ Stage 0 intake (manifest, design-intent, revisions).
    - Normalized branch: sg2/wolfram-embed-epic197 work already merged to main via
    PR #10; refreshed on local main. Untracked explorer.generated.html left in place.
    - validate_v5_packet: before=0 failures -> after=0 failures (5 expected pending_measuremen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
    [steel-tongue-drum.scad, visual-output-register.csv]
